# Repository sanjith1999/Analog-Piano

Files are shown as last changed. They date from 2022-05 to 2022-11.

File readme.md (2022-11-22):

## The Analog-Piano

The electronic pianos available in the markets are using a pre-recorded audio of the sound to generate the tones. The task of this project is explore the possible analog designs to synthesize a tone. In this report, we have discussed our views and experiences on a stable design for synthesizing middle octave c-Note. An audio amplifier design that improvises the generated sound quality and capable of driving mid-power speakers is included in parallel at each stage.

## Block Diagram
flow

## Circuit Diagram

### Amplifier
Capture

The complete report (downloadable) can be found [ here](https://github.com/sanjith1999/Analog-Piano/blob/master/Submission%20Files/Report/main.pdf)
<br>
<br>
### Breadboard Design
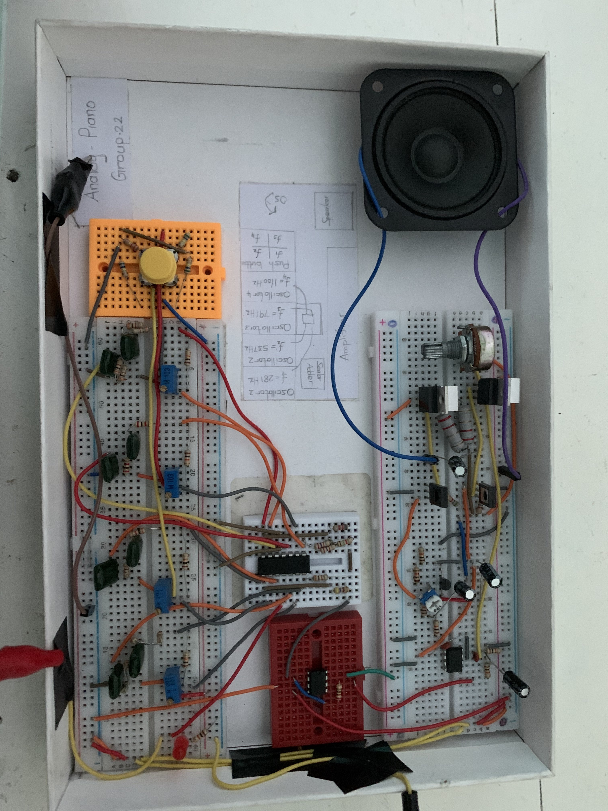
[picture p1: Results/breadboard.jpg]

<br>
<br>
<h3>Prototype</h3>
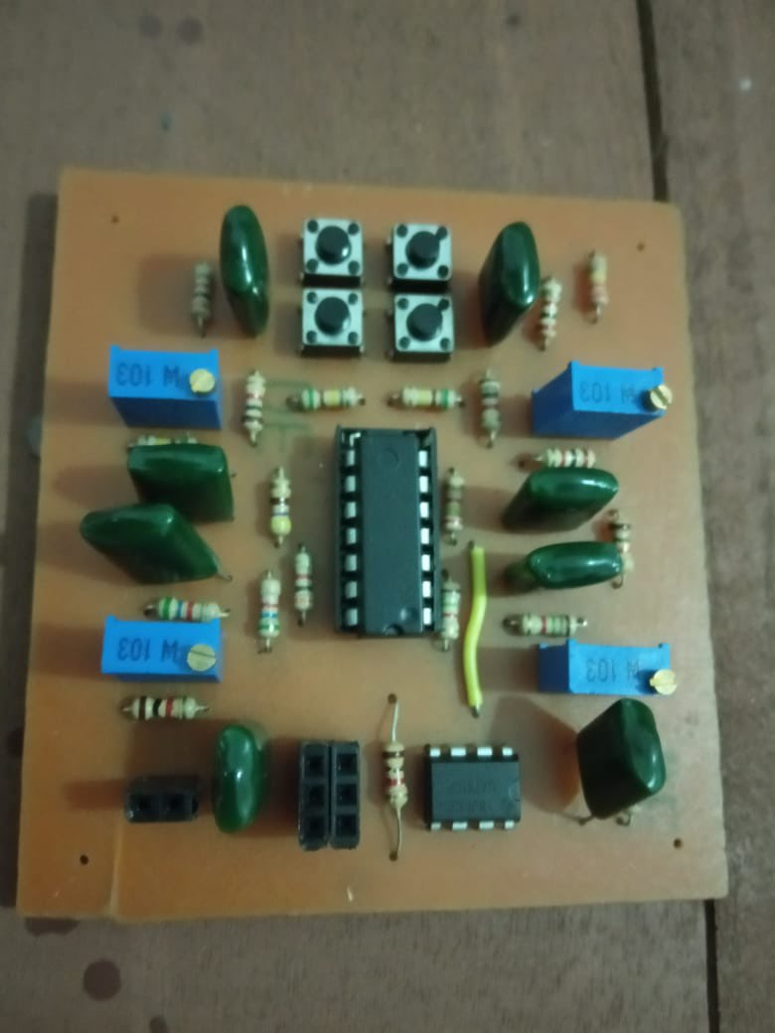
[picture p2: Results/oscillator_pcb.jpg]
Prototype Wave Generator

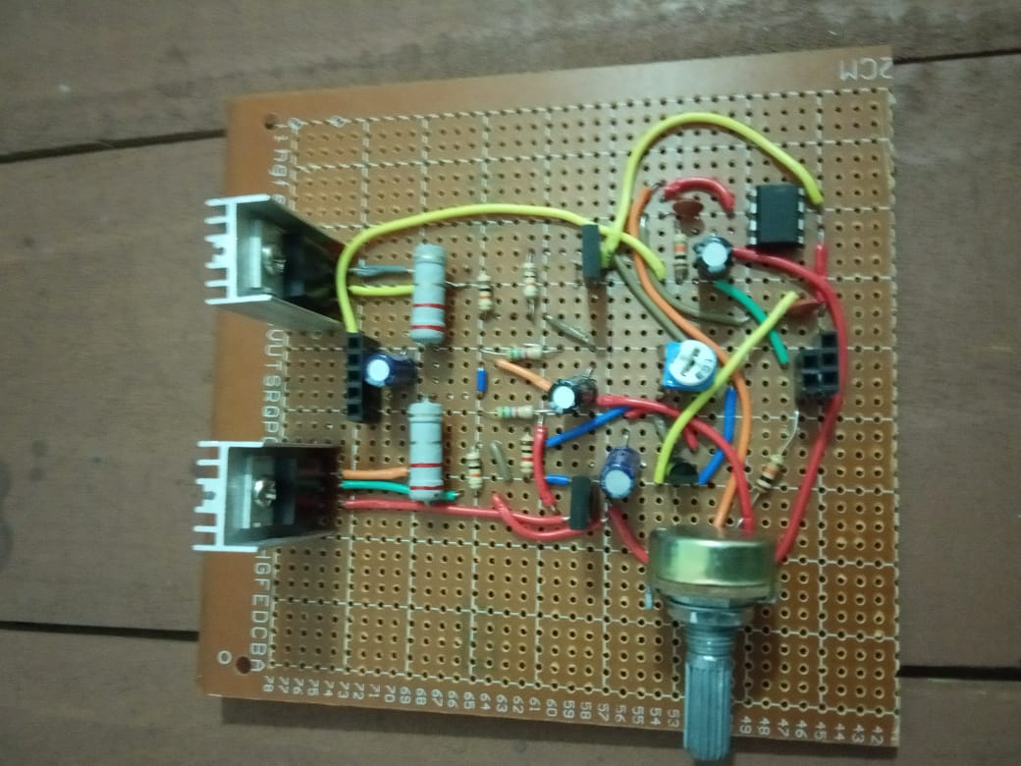
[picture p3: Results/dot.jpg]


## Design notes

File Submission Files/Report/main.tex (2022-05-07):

\documentclass[a4paper,12pt]{article}

\usepackage{./setting/preamble}
 
\begin{document}
\onecolumn
\input{sections/title}

\tableofcontents
\vspace*{1cm}
All the circuit virtual simulation circuits and results can be found \href{https://github.com/sanjith1999/Analog-Piano.git}{here.}
\vspace*{3cm}
\begin{abstract}
    The electronic pianos available in the markets are using a pre-recorded audio of the sound to generate the tones in a digital format. The task of this project is to explore the possible analog designs to synthesize a tone. In this report, we have discussed our views and experiences on a stable design for synthesizing middle octave c-Note. An audio amplifier design that improvises the generated sound quality and capable of driving mid-power speakers is included as the final stage of the design
\end{abstract}
\newpage

\twocolumn
\input{sections/introduction}
\input{sections/theory}
\newpage
\input{sections/methodology}
\newpage
\input{sections/results}
\input{sections/conclusion}
\newpage
\input{sections/appendix}
\end{document}

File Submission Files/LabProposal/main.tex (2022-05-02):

\documentclass[11pt]{article}

\usepackage{geometry}
 \geometry{
 a4paper,
 total={170mm,257mm},
 left=25mm,
 top=25mm,
 }

\title{Piano}
\author{Proposal : Group 22 }
\date{}
\date{\vspace{-5ex}}

\begin{document}
\maketitle
\section*{Description}
The piano can be considered as a simple starting point of fusing music into electronics.
The purpose of this project is to develop a piano with seven notes with only analog
electronic circuits.

\section*{Outcomes}
Design a piano that can generate sounds of frequencies associated with all the seven notes which
are sensible for the human ear. The piano sound must be amplified for the sake of making
it audible clearly. It is expected that the sound to be smoothened with noise-free
constraints to make it more enjoyable.
\subsection*{Skills}
\begin{enumerate}
    \item Hands-on experience with analog wave generation and wave addition.
    \item Designing amplifier circuits from scratch which can handle higher frequencies.
\end{enumerate}
\subsection*{Evaluation Criteria}
\begin{enumerate}
    \item Design: Neatness, and sustainability of the electronic circuit.
    \item Smoothness and audible level of output.
    \item The smoothness of sound during switching between notes.
\end{enumerate}

\section*{Additional Notes}
\begin{enumerate}
    \item Members are not allowed to use any kind of IC, Timers, or op-amps in the design of the project.
    \item Members are expected to have proper noise-cancelling strategies to make the sound enjoyable.
    \item Having a proper sound controlling mechanism to switch between sounds is considered a plus.
    \item Members are expected to implement techniques of pure wave generation and wave addition to achieve these requirements.
\end{enumerate}
\end{document}

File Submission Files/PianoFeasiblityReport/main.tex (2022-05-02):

\documentclass[10pt]{article}

\usepackage[left=3cm, right=3cm,top=2cm,bottom=2cm]{geometry}
\usepackage{tikz}
\usepackage{graphicx}
\usepackage{wrapfig}
\usetikzlibrary{shapes, arrows}

\font\myfont=cmr12 at 12pt
\setlength{\parindent}{8ex}

\newcommand\encircle[1]{\tikz[baseline=(X.base)] \node (X) [draw, shape=circle, inner sep=0] {\strut #1};}

\tikzstyle{block} = [draw, fill=red!20, rectangle,
minimum height=3em, minimum width=5em]
\tikzstyle{blockA} = [draw, fill=blue!20, rectangle,
minimum height=3em, minimum width=5em]
\tikzstyle{blockB} = [draw, fill=green!20, rectangle,
minimum height=3em, minimum width=5em]
\tikzstyle{sum} = [draw, fill=red!20, circle, node distance=2cm]
\tikzstyle{input} = [coordinate]
\tikzstyle{output} = [coordinate]
\tikzstyle{pinstyle} = [pin edge={-to,thin,black}]

\title{\bf{The Piano}}
\author{}
\author{\vspace{-2ex}}
\date{}
\date{\vspace{-2ex}}

\begin{document}

\begin{flushright}
    $_*$\underline{Group : 22}
\end{flushright}
\vspace{-10ex}
{\let\newpage\relax\maketitle}
\vspace{-12ex}
\section*{Introduction}
\vspace{-1.5ex}
Piano is one of the most pleasant musical instruments. It operates completely in a mechanical manner using vibration of differently tensed strings to produce musical notes. Our project idea is based on mimicking the operation using analog electronic components. Synthesizing signals with various frequencies and characteristics relevant to exact same notes which are produced by a real piano. This feasibility report will address the basic implementation strategies available in our analog design to generate a pleasant musical sound.
\vspace{-1ex}
\section*{Literature Review}
\vspace{-1.5ex}
Analog signal generator hidden inside the abstraction, is the starting point of most electronic circuits. Designs available in the market generate a variety of waveforms and frequency ranges according to the application. To generate a low-frequency sine-wave, available circuits engage a Wien bridge oscillator. This can be taken as the basic building block of piano since all tones can be visualized as the addition of different sine wave components. The concept of switching a connection with another circuit using a relay operation is common in analog design. This can be included in the piano design to mimic the action of the damping pedal.
\par
Old sound systems used an audio equalizer using RLC circuit to lower or boost certain frequency ranges specifically. This can be utilized in our piano to change the softness of the generated sound. In earlier days, most of the sound devices available in the market starting from simple analog radio up to studio speakers engaged voltage amplifiers to amplify the audio signal to a sustainable level. The circuit design of amplifiers also had the capability of removing dc offset which is a danger to the speaker.
\vspace{-1ex}
\section*{Block Diagram}
\begin{tikzpicture}[auto, node distance=3cm,>=latex']
    % We start by placing the blocks
    \node [blockA, name=keyInput] {key Input};
    \node [block, below of=keyInput,text width=2cm,yshift=1cm,xshift=1.5cm] (waveGenerator) {Wave Generator};
    \node[sum, right of =waveGenerator,text width=1cm,xshift=1cm](scalarAdder){Scalar Adder};
    \node[blockA, below of = keyInput,yshift=-1cm](pedal){Pedal};
    \node [block, right of = scalarAdder] (damper) {Damper};
    \node[block, below of = damper,yshift=1cm](switch){Relay Switch};
    \node [block, right of=damper,text width=2cm,, pin={[pinstyle]below:Extract Noise },node distance=3cm] (aE) {Audio Equalizer};
    \node[block, right of=aE](amplifier){Amplifier};
    \node[blockB,below of = amplifier,text width=2cm](speaker){Speaker Out};
    %\draw [->] (controller) -- node[name=u] {$u$} (system);
    %\node [output, right of=system] (output) {};

    % Once the nodes are placed, connecting them is easy. 
    \draw [draw,->] (keyInput.east) -| node {$\encircle{a}$} (waveGenerator.north);
    \draw [->] (waveGenerator) -- node {$\encircle{b}$} (scalarAdder);
    \draw[->](pedal) --node {} (switch);
    \draw[->](switch) --node {$\encircle{c}$} (damper);
    \draw[->](scalarAdder) --node {$\encircle{d}$} (damper);
    \draw[->](damper) --node {$\encircle{e}$} (aE);
    \draw[->](aE) --node {$\encircle{f}$} (amplifier);
    \draw[->](amplifier) --node {$\encircle{g}$} (speaker);
\end{tikzpicture}

\vspace{-8ex}
\section*{Analog Analysis}
\begin{itemize}
    \item[] $\encircle{a} : $ Analysing resistor values to be used in Wein-bridge that suit required frequency generation.
    \item[] $\encircle{b} : $ Pureness of sine waves generated with fundamental and over tone frequencies.
    \item[]  $\encircle{c} : $ Analysing the possiblity of switching and holding the damping operation.
    \item[] $\encircle{d} : $ Addition of the harmonic components according to the amplitude ratio.
    \item[] $\encircle{e} : $ Analyzation of exponential decay of audio signal.
    \item[] $\encircle{f} : $ Analyzing softness of sound by scaling different frequecy ranges.
    \item[] $\encircle{g} : $ Anlysing the output audio signal with different amplifiaction factor.
\end{itemize}

\section*{Methodology}

\subsubsection*{Analyzation of Piano Notes}
\vspace{-1.5ex}
Analyzing the frequency spectrum of sounds from each note of the piano, as to mimic the exact spectrum through the addition of sine waves.
\vspace{-1.5ex}
\subsubsection*{Wave Generation}
\vspace{-1.5ex}
We have decided to implement the Wein Bridge oscillator circuit to generate sine waves spans in the audio frequency range. The circuit allows modification of frequencies by interchanging values of resistance used. This character can be utilized to map the keys with corresponding wave generation.
\vspace{-1.5ex}
\subsubsection*{Damping of Audio Signals}
\vspace{-1.5ex}
As a step of mimicing the sound from Piano we need to decay the audio signal in an exponential manner. As of now, it is decided to implement some strategy to compensate the energy stored in wave inorder to get a decay in loudness with time.
\vspace{-1.5ex}
\subsubsection*{Amplification}
\vspace{-1.5ex}
As a step of getting audible sound from the piano, we decided to implement a amplifier circuit using  BJTs.
\vspace{-1.5ex}
\subsubsection*{Pedal Action}
\vspace{-1.5ex}
The action of damping pedals in the piano can be mimicked by changing the damping factor of the damper. As the initial step of implementing the pedal action, it is decided to isolate and engage the damper from the circuit in action.  To increase the closeness of the design with a real piano, it is also considered about including a switch to make the output sound softer in general.
\vspace{-1.5ex}
\subsubsection*{Audio Equalizer}
\vspace{-1.5ex}
Audio Equalizer softens the sound wave to give a pleasurable experience from the piano. The design of the equalizer consists of frequency filters.  It separates the sound signal under frequency categories and boosts or lowers its amplitude as per preference.
\vspace{-1.5ex}
\section*{Preliminary Results}
\vspace{-1.5ex}
As the early-stage process of our project, we were able to synthesize the sound of piano notes using only eight harmonics sine waves of corresponding frequecy. The following image shows the normalized frequency spectrum of original and regenerated audio signals. Although we were able to observe differences in damping patterns, the sounds of both the signals heard very much similar. It is also considered about implementing multiple dampers and adding compressed signals to bring the sound more magnetized towards the real one.
\begin{figure}[h]
    \centering
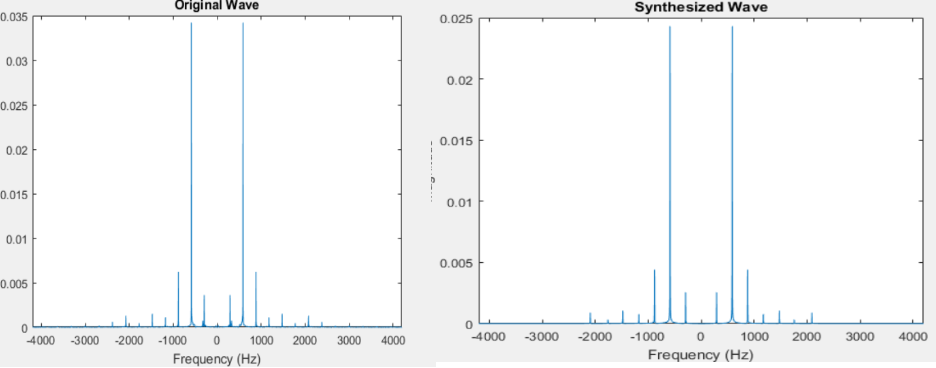
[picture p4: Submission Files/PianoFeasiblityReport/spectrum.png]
    
\end{figure}
\vspace{-1.5ex}
\section*{References}
1. Synthesizing Frequency of Notes $\to$ https://web.eecs.utk.edu/~hqi/ece505/project/proj1.pdf
\newline
2. Wave Generation $\to https://en.wikipedia.org/wiki/Wien$\_$bridge$\_$oscillator/$
\newline
https://www.homemade-circuits.com/simple-sine-wave-generator-circuits/
\newline
3. Mathematics of Sound $\to$ https://www.ams.jhu.edu/dan-mathofmusic/sound-waves/
\newline
4. Similar Project with High Scope $\to$ http://www.jiisuki.net/reports/howto-build-analog-synth.pdf
\newline
5. Audio Equalizer $\to$ https://circuitdigest.com/electronic-circuits/audio-equalizer-tone-control-circuit-with-bass-treble-and-mid-frequency-control

\end{document}

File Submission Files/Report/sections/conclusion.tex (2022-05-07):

\section{Conclusion}
We were able to complete the project within the given period. Most of the design expectations were achieved. From stable output waves from oscillator up to scaling of each harmonic in the spectrum were finely aligned with expectation. The stability in the gain of the output from the amplifier was adapted even in the situations of thermal-run-away. A better quality equalized sound is accomplished as the overall exploration of the project. 
\par
However, some of the design parameters could not be fully met. The phases of each harmonics could not be able to control rather than fine-tuning the oscillator gains. The amplifier design does not meet the expected efficiency and bandwidth range. While it meets the lower cutoff requirement, the upper cutoff is lower than(12kHz) expectation(20kHz). The best-achieved envelope pattern had elongation in the beginning. The final prototype on the PCB couldn't be able to complete due to the poor quality of the tracks.
\subsection*{Discussion}
\begin{itemize}
    \item Although the wave generator did a fine job with synthesizing c-wave, too many tuning parameters and complexity in combining oscillators make it hard to achieve such a feasible end-product as complete piano with this strategy.
    \item There is a large amount of heat dissipated by the TIP transistors. Heat sinks attached to them failed to compensate for enough heat in the longer run. Thermal-run-away behavior was observed which hindered circuit performance with time. 
    \item The values obtained by the virtual simulation did not agree with the values obtained through the physical prototype. However, the specification sheet has been based on the prototype values. Therefore, the specification sheet will be an accurate representation of the performance.
\end{itemize}
\onecolumn
\section*{References}
\begin{enumerate}
    \item \href{https://web.eecs.utk.edu/~hqi/ece505/project/proj1.pdf}{Synthesis of Musical Notes andInstrument Sounds with Sinusoids}
    \item \href{https://electronics.stackexchange.com/questions/178975/is-it-feasible-to-synthesise-sound-with-analog-circuitry-these-days}{Feasiblity about synthesizing sound with analog
              circuitry}
    \item \href{http://www.vibrationdata.com/piano.htm}{Original Sounds of Piano}
    \item \href{https://universe-review.ca/R12-03-wave02.htm}{Wave, Sound, and Music}
    \item  \href{https://en.wikipedia.org/wiki/Wien_bridge_oscillator}{Weinbridge-Oscillator}
    \item \href{https://www.homemade-circuits.com/simple-sine-wave-generator-circuits/}{Alternative sine wave generators}
    \item \href{https://www.ams.jhu.edu/dan-mathofmusic/sound-waves/}{Mathematics behind wave manipulation}
    \item \href{http://www.jiisuki.net/reports/howto-build-analog-synth.pdf}{How to Design and Build an Analog Synthesizer from Scratch}
\end{enumerate}
\vspace*{5cm}
\section*{Contribution}
\begin{tabular}{|l|l|l|}
    \toprule
    ID NO                    & Member                              & Contribution                                           \\
    \midrule\midrule
    \multirow{2}{*}{190562G} & \multirow{2}{*}{S.Sanjith}          & Damper Design, Improvisation of Amplfier Design,       \\
                             &                                     & Routing of PCBs, Data Sheet Design                     \\
    \midrule
    \multirow{2}{*}{190557V} & \multirow{2}{*}{K.G.C.P.Sandaruwan} & Oscillator Design, Scalar Adder Design                 \\
                             &                                     & Oscillator Schematic Design                            \\
    \midrule
    \multirow{2}{*}{190539T} & \multirow{2}{*}{T.Sajeepan}         & Analyzation of Original Wave, Amplifier Design(basic), \\
                             &                                     & Amplifier schematic design                             \\
    \midrule
    190543B                  & G.S.M.U.K.Samarakoon                & Contribution to Amplifier Design                       \\
    \bottomrule
\end{tabular}

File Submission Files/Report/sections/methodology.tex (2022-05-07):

\section{Methodology}
\subsection{Preliminary Analysis}
At an earlier stage of the project, it is planned to build an octave piano with twelve notes including minor keys. At that stage, we analyzed the frequency spectrum of each note and found out it is possible to produce a majority feeling of sound with only four harmonics to a given note.
\par
After synthesizing all the keynotes from its harmonics using Matlab, we moved to circuit development. At this stage, it is decided to stimulate only one note from the piano because the generation of notes is modularizable. For this purpose, the C-wave have chosen  which is in the middle of the spectrum.
\begin{figure}[h]
    \centering
    \begin{subfigure}{.9\columnwidth}
        \centering
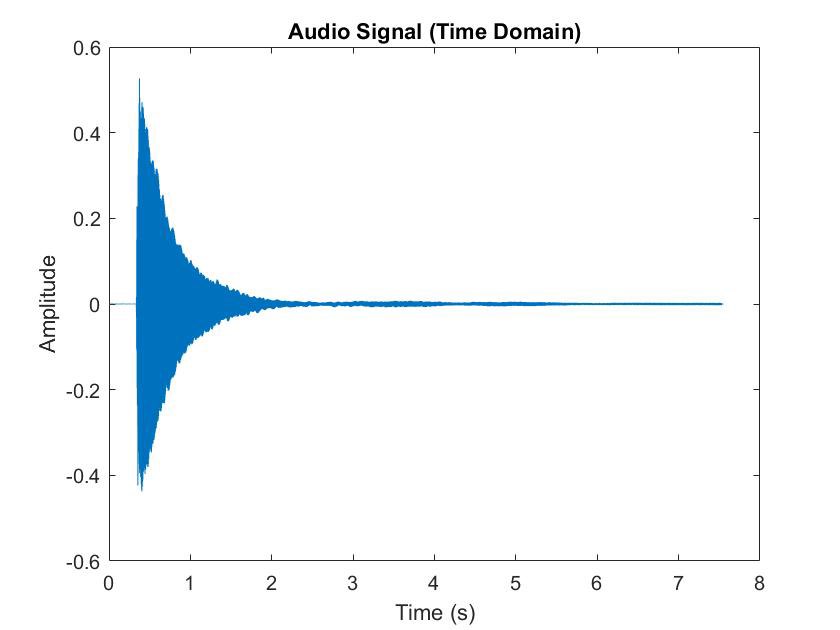
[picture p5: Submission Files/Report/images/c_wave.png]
        
    \end{subfigure}
    \newline
    \begin{subfigure}{.9\columnwidth}
        \centering
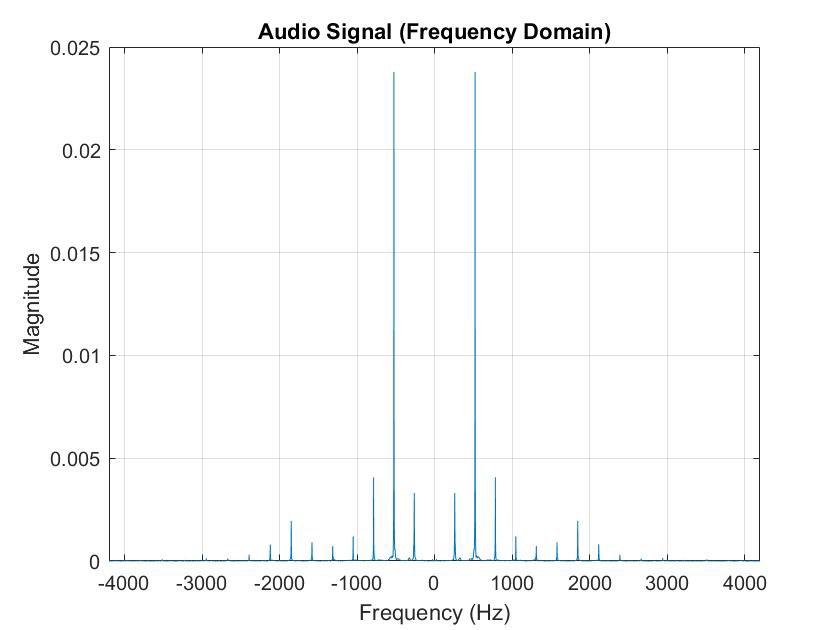
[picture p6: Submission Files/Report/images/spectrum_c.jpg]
        
    \end{subfigure}

\end{figure}
\subsection{Circuit Design}
The key components of the circuit are illustrated below in the block diagram. Before moving to the prototype all the circuits are simulated using NI Multism.Working simulation models of all the circuits can be found in the git-repository.
\begin{figure}[h]
    \begin{center}
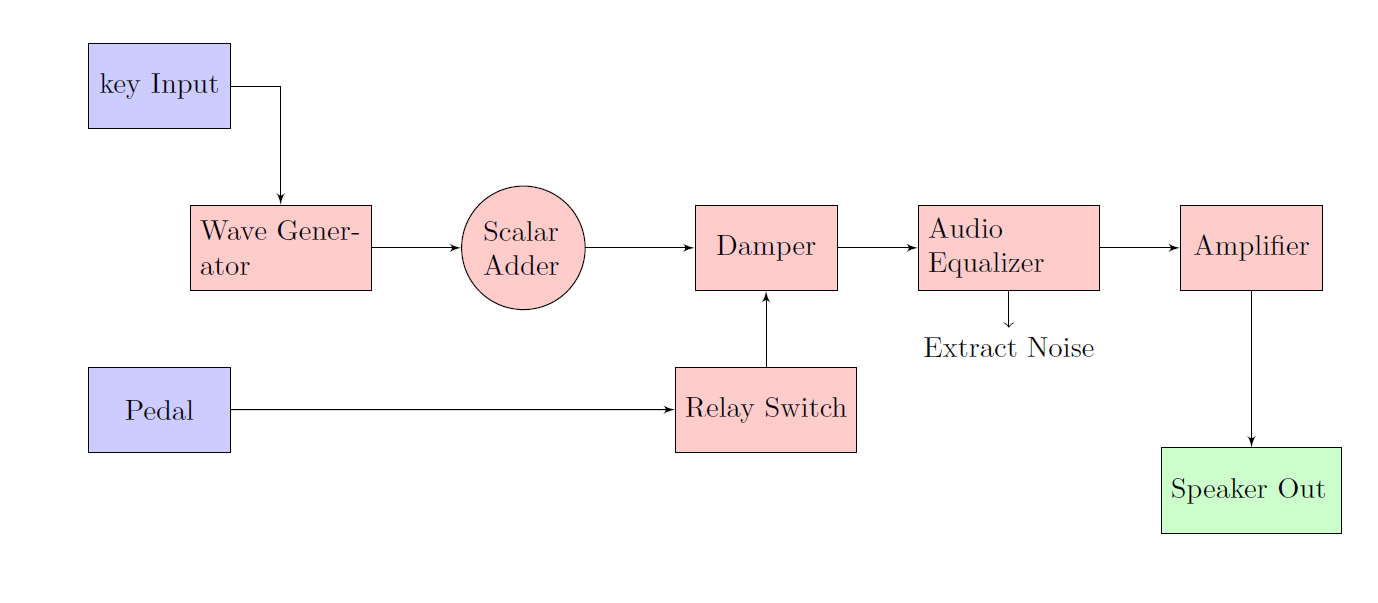
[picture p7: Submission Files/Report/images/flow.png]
        
        \caption*{Block Diagram of the Circuit}
    \end{center}
\end{figure}
\subsubsection{Wave Generator}
Square wave generation of half the frequency together with a bandpass active filter is considered in the first stage of the circuit development. Need for achieving a larger Q factor for the filter as the number of harmonics increases, lift the choice to not-feasible.
\par
Moving towards a stable solution brought the Wien bridge oscillator into play. These oscillators have the flexibility over frequency choice ($\frac{1}{2\pi RC}$) making them the most suitable option to be used with modularizable piano.
\subsubsection{Key and Pedal}
After a clear analysis of the waveform using Matlab, it is expected to achieve an exponential decay in the waveform once the oscillation is triggered. Looking at the discharging behavior of the capacitor initially it is decided to engage a capacitor together with an analog multiplier to form an envelope around wave output.
\par
Due to the power inefficiency of the design and difficulty in finding good quality multipliers, the design moved to engage tuning of negative feedback of oscillator to achieve necessary output. This is further utilized to mimic the damping pedal of the piano by controlling the elongation of the signal-out of each oscillator.
\subsubsection{Scalar Adder}
Direct connection between outputs of oscillators even after scaling leads to interference in the signal generation stage of the oscillator. In contrast, using a scaling adder we can provide a low impedance output path while scaling the inputs as specified.
\subsubsection{Amplifier}
At earlier stages, the amplifier was implemented in class-A configuration. The requirement for lower output resistance of the bias path leads to high power dissipation in the signal-free state. This made such a model not practical without huge heatsinks at the cost of low power efficiency.
\begin{figure}[h]
    \begin{center}
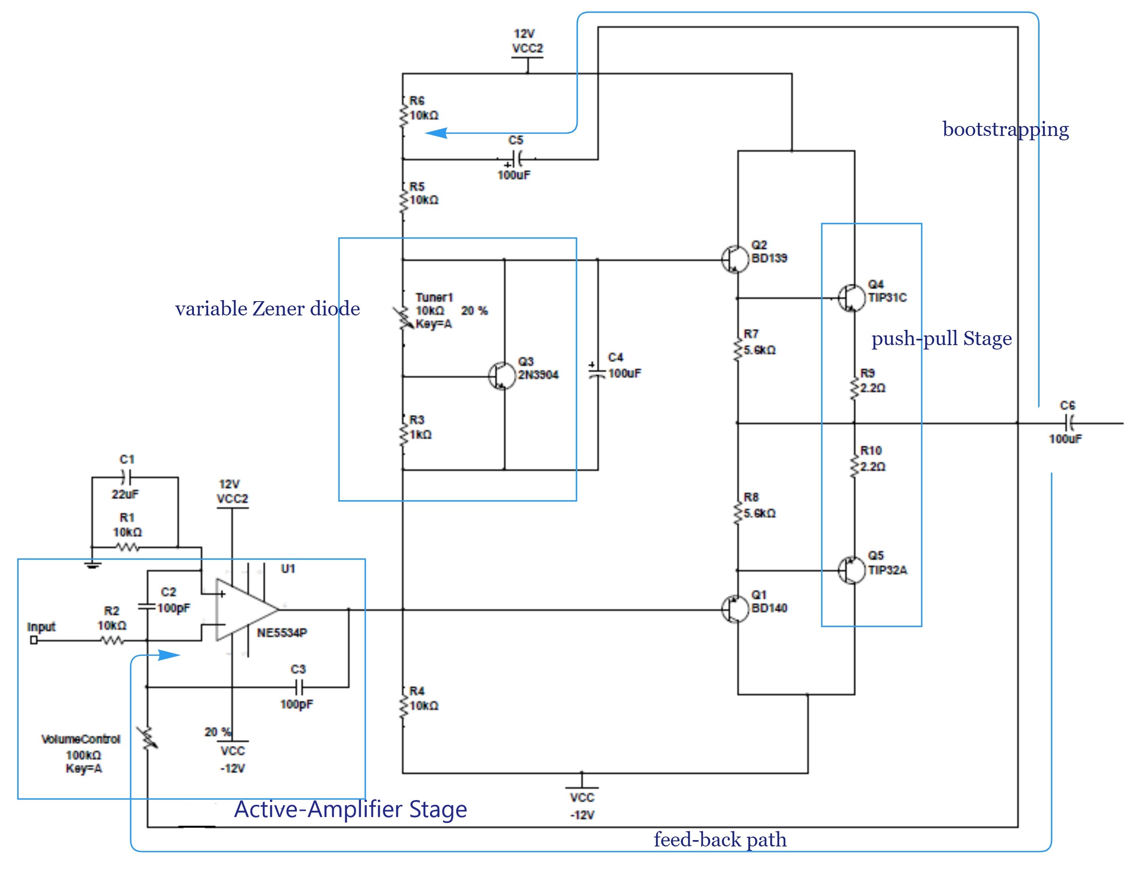
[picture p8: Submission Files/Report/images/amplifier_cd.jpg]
        
    \end{center}
\end{figure}
\\
\textbf{Active Amplifier Stage}: In the first part of the amplifier design an op-amp is used in the inverting configuration. The feedback path is connected to the end of the overall circuit to ensure enough current supply available in the output.\\
The op-amp NE5534 was chosen for the purpose according to its key characteristics such as high unity-gain bandwidth(10MHz), very low harmonic distortion,high common mode rejection ratio(100dB). The capacitance values of C2 and C3 are chosen to allow only higher frequencies ($>20kHz$) to pass through. These are utilized in a manner to remove high-frequency noises from the wave-form.
\\
\\
\textbf{Push-Pull Stage}: Considering the requirement of high power gain it is decided to engage Darlington pairs for this purpose. These components failed in the long run due to the inability of compensating for high power dissipation. Considering this, the design moved to engage two coupled BJTs to allow the choices for transistors to be used in the high current path. The similar pairs TIP31C and TIP32C were chosen after considering their high power compensation capability(around 40W).
\\
\\
\textbf{Bias}: Due to the requirement for a sudden supply of high current on the keypress, the signal gets noisy when we drive the speaker without any bias. In earlier stages, a few diodes are used to bias the circuit which failed to get rid of the noise. As the next step, we used Zener diodes that provide the capability to choose higher bias voltage. This results in the low efficiency of the circuit.
After considering all the methods it is decided to implement the variable Zener diode which has the flexibility over varying bias voltage in a wider range. This provides control over two extremities, effecieny and quality of the output.
\\
\\
\textbf{Bootstrapping}: The capacitor C5 gets charged to the pre-decided bias voltage.  By maintaining the circuit time constant very large ($t=R5\parallel R6\star C5>0.5S$) the overall bias voltage of the circuit is maintained at a constant value through-out the signal time.

\subsection{Prototype Design}
\begin{figure}[h]
    \begin{minipage}{.53\columnwidth}
        At earlier stages, a virtual prototype was developed using Multisim(see Appendix A), and many of the tests were carried out on this program itself. Afterward, the model is moved to the breadboard in a modular manner and the outputs at each stage were tested independently.
    \end{minipage}
    \begin{minipage}{.38\columnwidth}
        
    \end{minipage}
\end{figure}

As the final step of implementation, PCB for the physical prototype was designed using Altium (see Appendix B for layout). This was then screen printed and the relevant components soldered to the PCB. Finally, heatsinks were mounted accordingly to ensure safer operation.
\subsection{Components}
\subsubsection*{Wave Generator}
The resistance and capacitance values corresponding to the filter circuit of each frequency in the oscillator are indicated below in the table. The normalized content ratio and resistance used in the input path of the scalar adder are also appended together.
\begin{center}
    \begin{tabular}{|c|c|c|c|c|}
        \toprule
        f    & \multicolumn{2}{|c|}{Oscillator} & \multicolumn{2}{|c|}{Scaling}                         \\
        \cmidrule{2-5}
        (Hz) & R(k$\Omega$)                     & C(nF)                         & $\eta$ & R(k$\Omega$) \\
        \midrule
        281  & 5.67                             & \multirow{4}{*}{100}          & 0.1386 & 3.03         \\
        537  & 2.96                             &                               & 1      & 420          \\
        791  & 2.01                             &                               & 0.168  & 2.5          \\
        1087 & 1.44                             &                               & 0.051  & 8.33         \\
        \bottomrule
    \end{tabular}
\end{center}

Easily available 4-quad op-amp LM341 was chosen for oscillators. This allowed having a compact design in prototyping. UA751 op-amp is used in the scalar adder stage and 220$\Omega$ is used as feedback resistance to ensure the addition of all four waves sits in the supply range.
\subsubsection*{Amplifier}
The following list of elements is used in the amplifier stage to allow only the frequency in the audible range to pass through and to withstand high power dissipation.
\begin{enumerate}
    \item Capacitors :
          \begin{tabular}{l r}
              22$\mu$F  & 1 \\
              100$\mu$F & 1 \\
              100pF     & 2 \\
          \end{tabular}
    \item Resistors :
          \begin{tabular}{l r}
              10k$\Omega$  & 5 \\
              1k$\Omega$   & 1 \\
              5.6k$\Omega$ & 2 \\
          \end{tabular}
    \item Presets :
          \begin{tabular}{l r}
              10k$\Omega$  & 1 \\
              100k$\Omega$ & 1 \\
          \end{tabular}
    \item Power Resistors :
          \begin{tabular}{l r}
              2.2$\Omega$ & 2 \\
          \end{tabular}
    \item Transistors :
          \begin{tabular}{l r}
              2N3904        & 1 \\
              TIP31C,TIP32C & 1 \\
              BD139,BD140   & 1 \\
          \end{tabular}
    \item Op-Amp : NE5534P   1
\end{enumerate}

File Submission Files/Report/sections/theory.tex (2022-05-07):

\section{Theory}
\subsection{Oscillator}
\begin{wrapfigure}{l}{0.50\columnwidth}
  \vspace*{-.5cm}
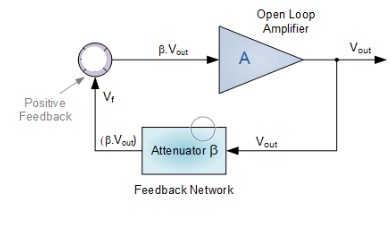
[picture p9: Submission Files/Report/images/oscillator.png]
  
  \vspace*{-.8cm}
\end{wrapfigure}

An oscillator is an amplifier that uses positive feedback that generates an output frequency without the use of an externally applied input signal. Once the oscillation is started, the parameters A and $\beta$ are aligned to maintain a unity gain at the required frequency in order to keep the oscillation indefinitely stable.

\subsubsection*{Wein-Bridge Oscillator}
The Wien Bridge Oscillator uses a feedback circuit consisting of a series RC node cascaded with a parallel RC of the same component values producing a phase delay or phase advance circuit depending upon the frequency. Effectively they act as a second-order frequency dependant Band-Pass-Filter with a high Q factor at the selected frequency $f_r=\frac{1}{2\pi RC}$. This RC network is connected in the positive feed-back path of the amplifier and has zero phase shift at just one frequency.
\par
Other part of the feedback signal is connected to the inverting input terminal(negative feed-back) via resistor divider network of $R_1\&R_2$. Then at the selected resonant frequency($f_r$), the voltages applied to the inverting and non-inverting inputs will be equal and “in-phase”. So the positive feedback will cancel out the negative feedback signal causing the circuit to oscillate.

\begin{figure}[h]
  \begin{subfigure}{.58\columnwidth}
    \centering
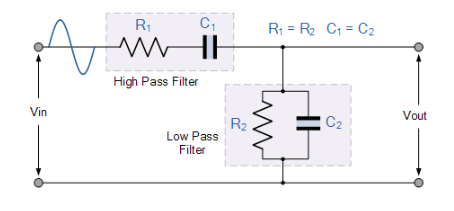
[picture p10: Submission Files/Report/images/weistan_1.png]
    
    \caption*{RC-Network}
  \end{subfigure}
  \begin{subfigure}{.38\columnwidth}
    \centering
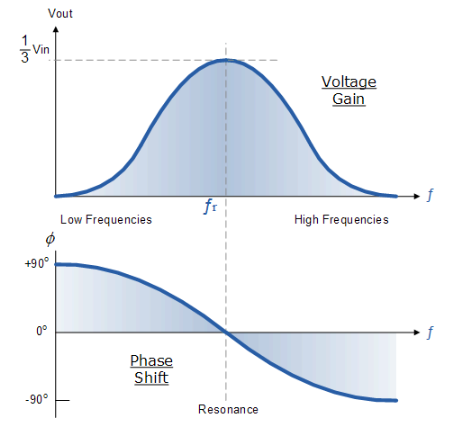
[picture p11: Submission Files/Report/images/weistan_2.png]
    
    \caption*{Response}
  \end{subfigure}
  \newline
  \centering
  \begin{subfigure}{.65\columnwidth}
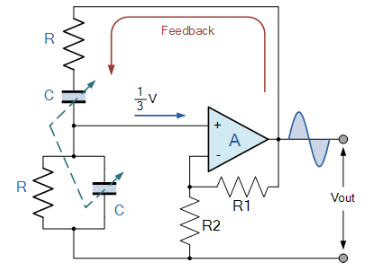
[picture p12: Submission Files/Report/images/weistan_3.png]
    
    \caption*{Oscillator}
  \end{subfigure}
\end{figure}
\subsubsection*{Starting and Damping Oscillation}
By controlling the negative feedback ratio($\frac{R_2}{R_1+R_2}$) of the oscillator we can start and damp the oscillation as required. To start oscillation, we need to slightly reduce the negative feedback($<\frac{1}{3}$). This will give rise to a resultant signal on the amplifier input side which is get amplified and fed back recursively turns out to drive oscillation.
\par
Keeping the feedback ratio slightly more ($>\frac{1}{3}$) will give rise to a resultant negative input which is get added adversely with output resulting in damping of the oscillation. By fine-tuning the ratio in a very elegant manner, it is possible to control the damping time constant.
\subsection{Amplifier}
Driving a high-power (3W) speaker draws a high amount of current from the circuit. These current ranges are very much higher than the maximum supply available from op-amps and other low power components used in generating the wave patterns. So it is crucial to maintain an amplifier boundary between low power noisy signal to high power driving signal free of noise. In the following context, we will discuss the theories behind our amplifier design in detail.
\subsubsection*{Class-A }
\begin{figure}[h]
  \begin{center}
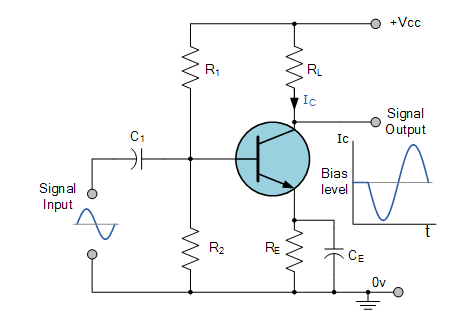
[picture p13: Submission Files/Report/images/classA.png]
    
    \vspace*{-.5cm}
  \end{center}
\end{figure}
These are the simplest configuration among other families. It uses a single-ended transistor for its output stage with the resistive load connected directly to the Collector terminal. When the transistor switches “ON” it sinks the output current through the Collector resulting in an inevitable voltage drop across the Emitter resistance thereby limiting the negative output capability.
\par
The current handling capability of such an amplifier family can be increased drastically by replacing the output transistor with the structure of \textbf{Darlington pair}. These devices provide high input impedance.
\subsubsection*{Class-B}
Class B Amplifiers are biased to only conduct half of the input signal. Using 2 such amplifiers arranged in a “Push-Pull” configuration, and combining the output signal, the full waveform can be obtained.
\par
As the quiescent current for this amplifier is 0, there is little or no DC, therefore much less power dissipation. However, there is a slight waveform distortion due to the bias voltage requirement of the transistor known as cross-over distortion.
\subsubsection*{Class-AB}
Class AB amplifiers overcome the distortion issue of class B amplifiers by permanently bringing the two transistors just into the active region. This reduces the efficiency, but results in an undistorted the waveform in the output.
\par
\begin{figure}[h]
  \vspace*{-.2cm}
  \begin{center}
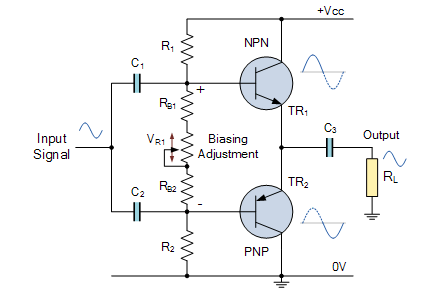
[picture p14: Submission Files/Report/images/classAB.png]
    
  \end{center}
  \vspace*{-.5cm}
\end{figure}
As the power dissipation due to the DC component is much less than class A amplifiers, these circuits allow the use of compact heat sinks during the operation.
\subsubsection*{Variable Zerner Diode}
\begin{figure}[h]
  \begin{minipage}{.68\columnwidth}
    This variable Zener diode circuit acts like a Zener diode with a breakdown voltage adjustable in a vast domain. This is achieved by driving a BJT in the active region and controlling the base current.
  \end{minipage}
  \begin{minipage}{.3\columnwidth}
    \begin{center}
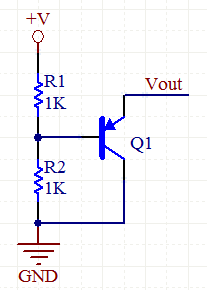
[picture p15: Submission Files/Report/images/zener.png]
      
    \end{center}
  \end{minipage}
  \vspace*{-.5cm}
\end{figure}
The current through the voltage divider $R_1\&R_2$ must be higher compared to the base current.

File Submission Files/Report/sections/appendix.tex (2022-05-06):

\appendix
\section{Circuit Design}
\subsection*{Wave Generator}
\begin{figure}[h]
    \centering
    
    \vspace*{-5cm}
\end{figure}
\subsection*{Amplifier}
\begin{figure}
    \centering
    \vspace*{-6.5cm}
    
\end{figure}
\newpage

\section{Layout}
\begin{figure}[h]
    
    \begin{subfigure}{\textwidth}
        \centering
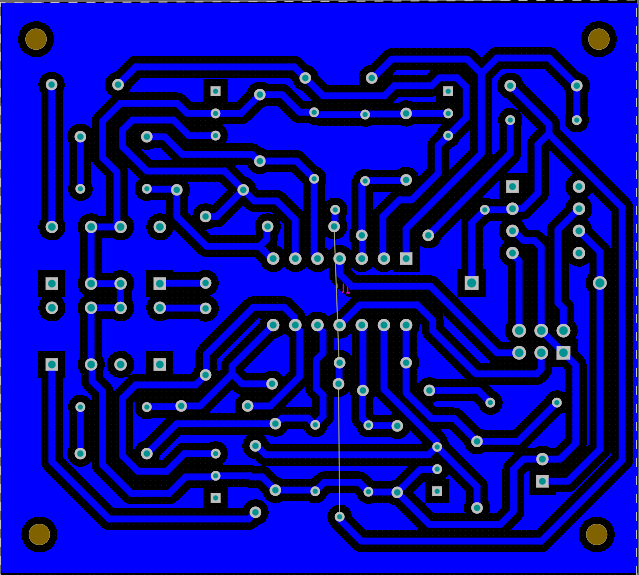
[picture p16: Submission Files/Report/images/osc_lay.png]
        
        \caption{\textbf{PCB-I} : Wave Generator}
    \end{subfigure}
    \vspace*{.5cm}
    \begin{subfigure}{\textwidth}
        \centering
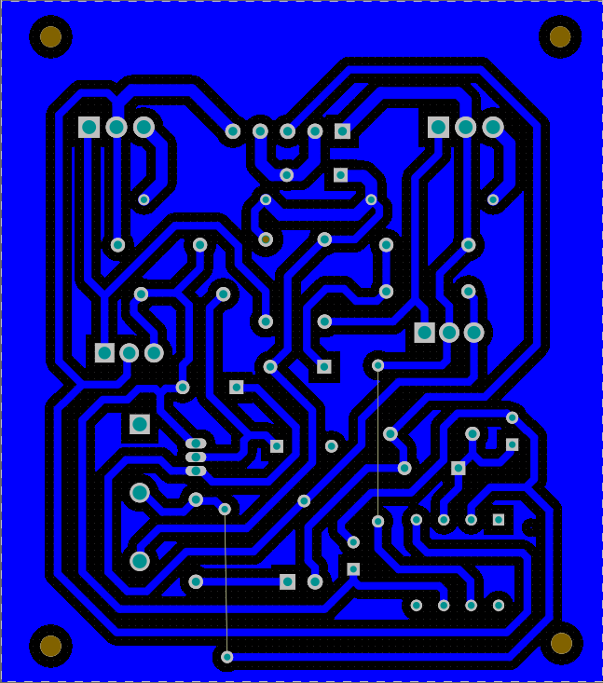
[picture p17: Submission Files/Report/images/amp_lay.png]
        
        \caption{\textbf{PCB-II} : Amplifier}
    \end{subfigure}
\end{figure}
\section{Datasheet}
The datasheet of the model is as follows...
\includepdf[pages=-]{sections/datasheet}

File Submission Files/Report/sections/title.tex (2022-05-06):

\begin{titlepage}

    \center

    % University
    \textsc{\Large Department of Electronic and Telecommunication}\\[.4cm]
    \textsc{\Large University of Moratuwa}\\[1cm]

    % Document info
    \textsc{\Large EN2090 : LABORATORY PRACTICE-II}\\[0.2cm]
    \textsc{\large }\\[1cm] 										% Course Code
    \HRule \\[0.5cm]
    { \LARGE \bfseries The Analog-Piano}\\[0.3cm]
    \HRule \\[1.5cm]
    \large
    \begin{center}
        \begin{tabular}{l l}
            \multicolumn{2}{c}{\textbf{Team : Dream Epic}} \\\\
            S.Sanjith  & 190562G \\
            T.Sajeepan & 190539T \\
            K.G.C.P.Sandaruwan  & 190557V \\
            G.S.M.U.K.Samarakoon & 190543B \\
        \end{tabular}
    \end{center}
\vspace*{1cm}
    {\Large \today}\\[1cm]
    \\[2cm] 
    \HRule\\
    \begin{flushleft}
        \vspace*{-.4cm}
        \emph{Our sincere thanks to Mr.Bhanuka Silva.}
    \end{flushleft}
    \vfill
\end{titlepage}

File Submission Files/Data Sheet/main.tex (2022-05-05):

\documentclass[a4paper,12pt,oneside,pdflatex,italian,final,twocolumn]{article}

\usepackage[utf8]{inputenc}
\usepackage{parallel}
\usepackage{siunitx}
\usepackage{booktabs}
\usepackage{fancyhdr}
\usepackage{caption}
\usepackage{multirow}
\usepackage{gensymb}
\usepackage[export]{adjustbox}
\usepackage[margin=0.5in]{geometry}
\addtolength{\topmargin}{0in}

\usepackage{libertine}
\renewcommand*\familydefault{\sfdefault}  %% Only if the base font of the document is to be sans serif
\usepackage[T1]{fontenc}

\graphicspath{{./images/}}

\title{Piano Datasheet}
\author{Team : Dream Epic }
\date{\today}

\begin{document}

\pagestyle{fancy}

\lhead{ENTC}
\chead {\today}
\rhead{Datasheet v1}

\onecolumn

\begin{figure}
    \begin{minipage}{0.47\textwidth}
        \centering
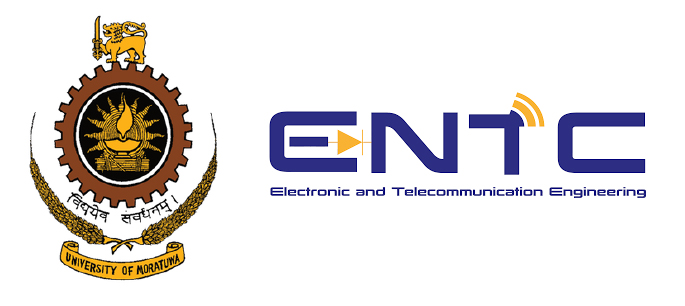
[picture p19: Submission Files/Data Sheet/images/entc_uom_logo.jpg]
        
    \end{minipage}
    \hfill
    \begin{minipage}{0.47\textwidth}
        \raggedleft
        \Huge \textbf{The Analog Piano}
    \end{minipage}
\end{figure}

\begin{figure}
    \begin{minipage}{0.65\textwidth}
    \section{Overview}
 The device is a sound synthesizer that mimics the sound of c-wave similar to that of a piano, on keypress.  A speaker(8$\Omega$ preferred) ranges around 3W can be used with the pinout to observe the sound output. The volume of the speaker and the noise level can be adjusted according to user interest. The components in the device can be adjusted according to one's interest to mimic a complete piano by implementing many such modules. The amplifier alone can be used to drive small speakers from the low power signal output of simple devices such as mobile phones. 
    \end{minipage}
    \hfill
    \begin{minipage}{0.3\textwidth}
        \centering
        
    \end{minipage}
\end{figure}

\section{Description}
As illustrated in the block diagram below the device consist of four oscillators which are fired by a push button. These oscillators mimic the first four harmonics which are strong enough to model the c-keynote. The triggered signals get added and scaled accordingly through a scalar adder. The output is filtered and amplified before reaching the speaker. Damping time of the wave can be controlled via the damping mechanism attached through a variable resistor with each oscillator. These can be used to mimic the functionality of the damping pedal by increasing their values.
\par
The preset in the amplifier block is allowed to tune by the user to get a noise-free output. For longer usage, it is recommended to keep the preset at a lower value which affects the power efficiency of the circuit. It is expected to use the device not more than fifteen minutes continuously which may harm the operation of the amplifier. Heat sinks used in the amplifier can reach up to 100$\degree$C. It is not advisable to touch them during the continuous operation of the synthesizer.
\par
The maximum current drawn by the oscillator and scalar adder is less than 5mA. Due to such a lower requirement, it is omitted in the technical specifications.
\begin{figure}[h]
    \centering
    
    \caption{Circuit Block Diagram}
\end{figure}
\newpage
\section{Technical specification}
Specifications are indicated for each module even though it pin-out of the device is narrower. This is done in the belief of allowing the users to make use of this to combine such modules in the creation of complete piano.\\
\vspace{-.5cm}
\begin{figure}[h]
\begin{minipage}{\textwidth}
\begin{center}
\begin{tabular}{|c|c|c|c|}
     \multicolumn{4}{l}{\textbf{Oscillators}}\\
    \toprule
     Operational  & Operational  & Decaying Control  & Output \\
     Voltage(V) & Frequencies(Hz)& Range(ms) & Impedance($k\Omega$)\\
    \midrule
   \multirow{4}{*}{3-6} & 281$\pm$3 & 300$\pm$100 & 2.49 \\
     & 537$\pm$3 & 300$\pm$120 & 0.44 \\
     & 790$\pm$5 & 300$\pm$150 & 2.37 \\
     & 1100$\pm$5 & 300$\pm$200 & 7.43 \\
    \bottomrule
\end{tabular}
\end{center}
\end{minipage}

\begin{minipage}{\textwidth}
\vspace{.8cm}
\begin{center}
    \begin{tabular}{|c|c|c|c|}
     \multicolumn{4}{l}{\textbf{Scalar Adder}}\\
    \toprule
     Operational  & Allowed Frequency & Recommended Resistance  & Output \\
     Voltage(V) & Range(Hz) & Range($k\Omega$) & Impedance($k\Omega$)\\
    \midrule
    9-12 & 20-20000 & 0.5-50 & 4.53\\
    \bottomrule
\end{tabular}
\end{center}
\end{minipage}

\begin{minipage}{\textwidth}
\vspace{.8cm}
\begin{center}
    \begin{tabular}{|l|c|c|}
     \multicolumn{3}{l}{\textbf{Amplifier}}\\
    \toprule
       & Unit & Value \\
    \midrule
    Operational Voltage & V & 9-12\\
    Current Requirements & A &0.08-0.5\\
    Input Impedance(Ac) & $M\Omega$ & 43$\pm$5\\
    Output Impedance(Ac) & $\Omega$&$10\pm5$\\
    Operational Frequency Range & Hz &200-12000\\
    Volume Control Range & dB & 20-70\\
    Achievable Power Efficiency &  & 63\%\\
    
    \bottomrule
\end{tabular}
\end{center}
\end{minipage}
\end{figure}

\raggedright
\vspace{-.5cm}
\section{Pinout}
\begin{minipage}{.48\textwidth}
\begin{center}
    \begin{tabular}{|c|c|}
     \multicolumn{2}{l}{\textbf{PCB-I : Wave Generator}}\\
    \toprule
        Pin & Signal \\
    \midrule
        \multicolumn{2}{|l|}{P1}\\
    \midrule
    1 & Ground \\
    2 & Power Supply +10.5$\pm$1.5\\
    3 & Power Supply -4$\pm$1\\
    4 & Ground \\
    5 & Power Supply +4$\pm$1\\
    6 & Power Supply -10.5$\pm$1.5\\
    \midrule
        \multicolumn{2}{|l|}{P2}\\
    \midrule
    1 & Signal Out\\
    2 & Ground\\
    \bottomrule
\end{tabular}
\end{center}
\end{minipage}
\begin{minipage}{.48\textwidth}
\begin{center}
    \begin{tabular}{|c|c|}
     \multicolumn{2}{l}{\textbf{PCB-II : Amplifier}}\\
    \toprule
        Pin & Signal \\ 
    \midrule
    \multicolumn{2}{|l|}{P1}\\
    \midrule
    1 & Signal In\\
    2 & Ground\\
    \midrule
    \multicolumn{2}{|l|}{P2}\\
    \midrule
    1 & Power Supply +10.5$\pm$1.5\\
    2 & Audio Out\\
    3 & Ground\\
    4 & Audio Out\\
    5 & Power Supply -10.5$\pm$1.5\\
    \bottomrule
\end{tabular}
\end{center}
\end{minipage}
\newpage
\section{Fine-Tuning}
\vspace{-0.2cm}
\begin{enumerate}
    \item \textbf{Wave Generator} : The resistance values of multi-turn presets  R5, R13, R22, and R2 can be adjusted to achieve different damping time constant of the output wave. These are corresponding to frequencies 1100Hz, 790Hz, 537Hz, and 281Hz respectively. Users also have the flexibility to change R8, R17, R23, and R15 in an inversely proportional manner to vary the proportional constants of those frequencies on the final wave output.
    \vspace{-.3cm}
    \item \textbf{Amplifier} : The resistance value of the preset RP can be adjusted according to the power required to achieve different audio levels in the speaker output. Keeping the resistance values around 2K$\Omega$ is recommended for longer usage.
\end{enumerate}

\vspace{-1cm}
\section{Measurements}
\vspace{-.4cm}
\begin{figure}[h]
    \begin{minipage}{0.45\textwidth}
        \centering
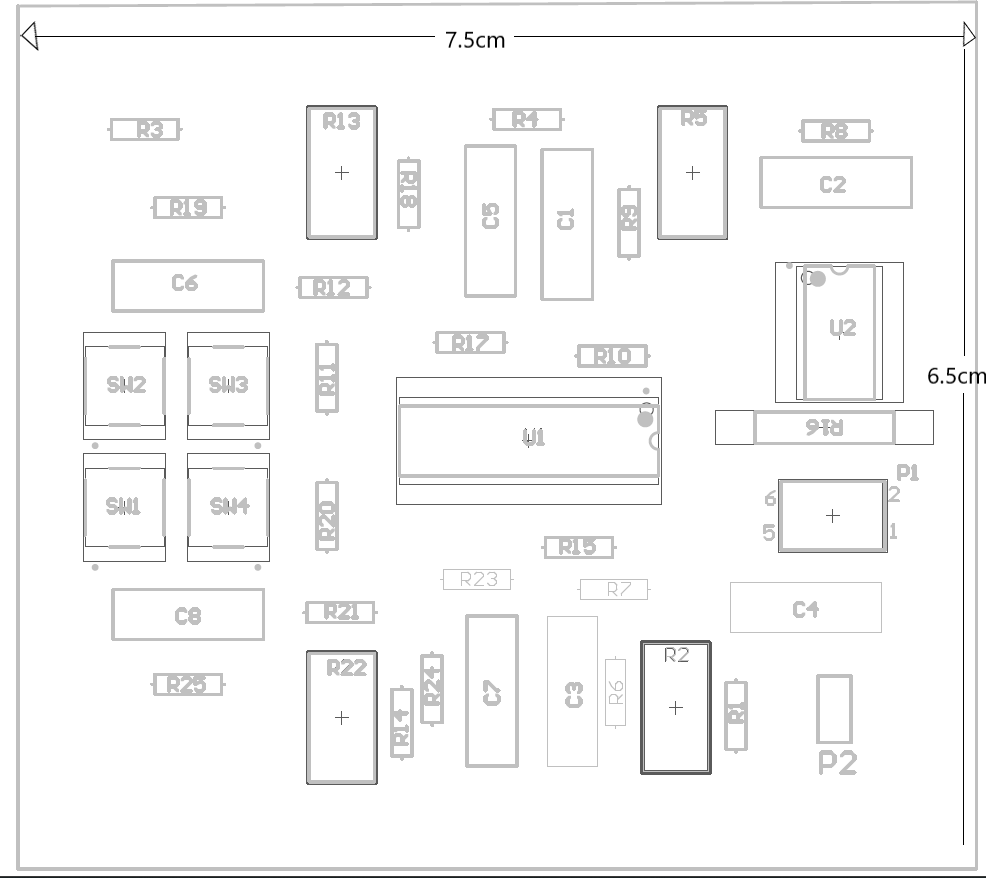
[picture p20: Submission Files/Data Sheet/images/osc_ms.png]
        
        \caption*{PCB-I : Wave Generator}
        \label{pcb_1}
    \end{minipage}
        \hfill
        \begin{minipage}{0.45\textwidth}
        \centering
        
        \caption*{PCB-II : Amplifier}
        \label{pcb_2}
    \end{minipage}
\end{figure}
\vspace{-1.3cm}
\section{Application Curves}
\vspace{-.2cm}
The output wave pattern(\ref{wave}) and its spectrum(\ref{spectrum}) at the end of wave generator are indicated in the following figures. The damping time constant can be elongated via the variable resistor attached to each oscillator.
\begin{figure}[h]
    \begin{minipage}{0.47\textwidth}
        \centering
        
        \caption{Final Wave Pattern}
        \label{wave}
    \end{minipage}
        \hfill
        \begin{minipage}{0.47\textwidth}
        \centering
        
        \caption{Frequency Spectrum}
        \label{spectrum}
    \end{minipage}
\end{figure}

The magnitude response(\ref{magnitude}) and phase response(\ref{phase}) of the amplifier are indicated below. The amplifier is suitable for frequencies ranging from 0Hz to 12kHz. This is visible from the facts that the overall gain is maintained at a constant value according to the volume control and the phase is maintained at -180$\degree$ in that range.
\begin{figure}[h]
    \begin{minipage}{0.47\textwidth}
        \centering
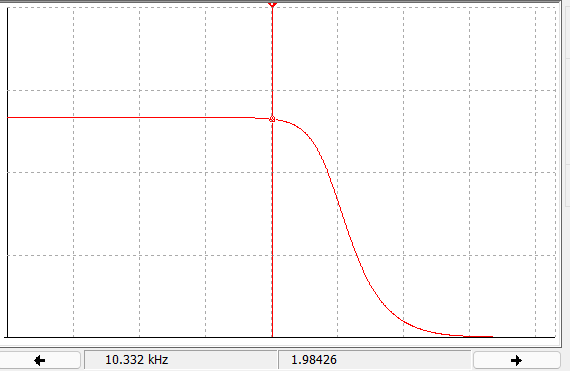
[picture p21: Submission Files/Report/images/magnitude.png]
        
        \caption{Magnitude}
        \label{magnitude}
    \end{minipage}
    \hfill
    \begin{minipage}{0.47\textwidth}
        \centering
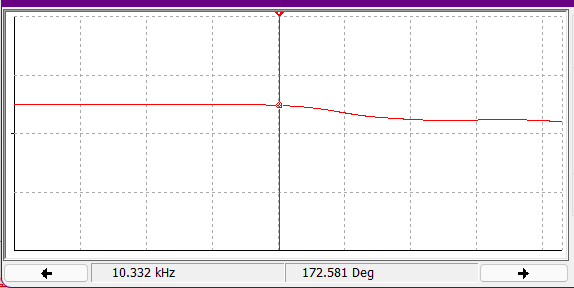
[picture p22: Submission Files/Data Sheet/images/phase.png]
        
        \caption{Phase}
        \label{phase}
    \end{minipage}
\end{figure}

\begin{figure}[p]
\begin{center}
\vspace{-4cm}
    
\end{center}
\end{figure}
\begin{figure}[p]
\begin{center}
\vspace{-5cm}
    
\end{center}
\end{figure}
\end{document}

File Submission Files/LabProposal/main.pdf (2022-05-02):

## Piano

Proposal : Group 22

## Description

The piano can be considered as a simple starting point of fusing music into electronics. The purpose of this project is to develop a piano with seven notes with only analog electronic circuits.

## Outcomes

Design a piano that can generate sounds of frequencies associated with all the seven notes which are sensible for the human ear. The piano sound must be amplified for the sake of making it audible clearly. It is expected that the sound to be smoothened with noise-free constraints to make it more enjoyable.

Skills

1. Hands-on experience with analog wave generation and wave addition.
2. Designing amplifier circuits from scratch which can handle higher frequencies.

Evaluation Criteria

1. Design: Neatness, and sustainability of the electronic circuit.
2. Smoothness and audible level of output.
3. The smoothness of sound during switching between notes.

## Additional Notes

1. Members are not allowed to use any kind of IC, Timers, or op-amps in the design of the project.
2. Members are expected to have proper noise-cancelling strategies to make the sound enjoyable.
3. Having a proper sound controlling mechanism to switch between sounds is considered a plus.
4. Members are expected to implement techniques of pure wave generation and wave addition to achieve these requirements.

1

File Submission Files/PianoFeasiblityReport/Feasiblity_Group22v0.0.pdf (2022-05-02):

∗Feasiblity Report → Group : 22

# The Piano

## Literature Review

The Analog signal generator design is a common project around the senior years of EN2090 module from the ENTC department. It engaged the circuit design of the Wien bridge oscillator, as a low-frequency sine wave generator. It can be utilized to produce sine waves in the audio frequency range. Analog electronic musical instrument designs available in the market engaged the concept of modulation with a sine wave to get a sudden change in frequency output. This strategy can be mimicked to implement a pedal design that can deliver an experience of sudden change in sound pitch.
Old speakers used an audio equalizer using RLC circuit to lower or boost certain frequency ranges specifically. This can be utilized in our piano to change the softness of the generated sound. In earlier days, most of the sound devices available in the market starting from simple analog radio up to studio speakers engaged voltage amplifiers to amplify the audio signal to a sustainable level. The circuit design of amplifiers also had the capability of removing dc offset which is a danger to the speaker.

## Block Diagram

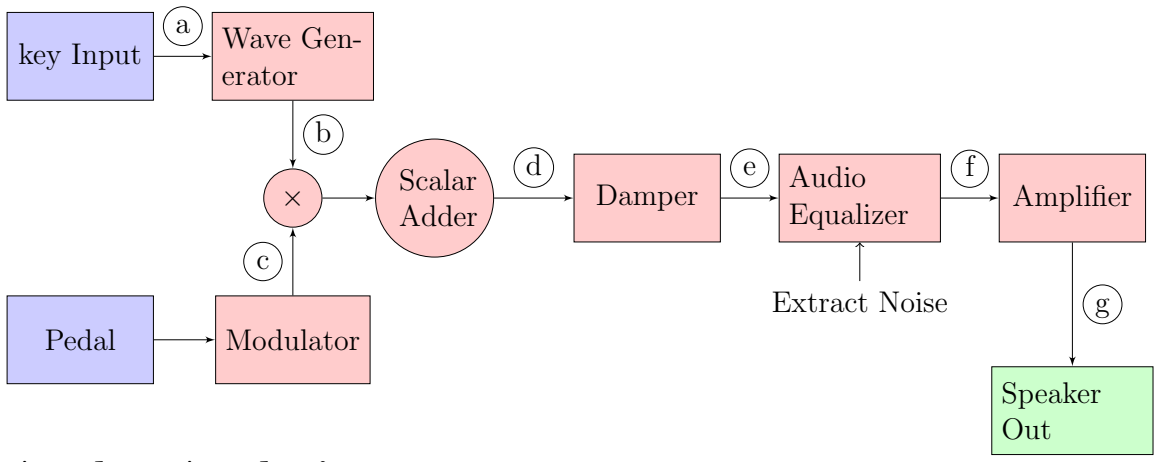
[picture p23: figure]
key Input; Wave Gen-; erator; Scalar Adder; Pedal; Modulator; Damper; Audio; Equalizer; Extract Noise; Amplifier; Speaker Out

## Analog Analysis

a : The effect resistor values in frequeny of the wave generation.

b : Pureness of sine waves generated with fundamental and over tone frequencies.

c : Modulation with a sine wave to get a higher octave.

d : Addition of the harmonic components according to the amplitude ratio.

1

e : Analyzation of exponential decay of audio signal.

f : Analyzing softness of sound by scaling different frequecy ranges.

e : Anlysing the output audio signal with different amplifiaction factor.

## Methodology

Analyzation of Piano Notes
Analyzing the frequency spectrum of sounds from each note of the piano, as to mimic the exact spectrum through the addition of sine waves.

Wave Generation
We have decided to implement the Wein Bridge oscillator circuit to generate sine waves spans in the audio frequency range. The circuit allows modification of frequencies by interchanging values of resistance used. This character can be utilized to map the keys with corresponding wave generation.

Damping of Audio Signals
As a step of mimicing the sound from Piano we need to decay the audio signal in an exponential manner. As of now, it is decided to implement the strategy used in envelope detector as to get an exponential decay in sound.

Amplification
As a step of getting audible sound from the piano, we decided to implement a non inverter amplifier circuit using operational amplifier.

Modulation
Inorder to observe sudden change in octave on the pedal press, it is decided to implement a modulator. Modulator design consist of a simple wave generator of required frequency and wave Multiplication.

Audio Equalizer
Audio Equalizer softens the sound wave to give a pleasurable experience from the piano. The design of the equalizer consists of frequency filters. It separates the sound signal under frequency categories and boosts or lowers its amplitude as per preference.

## References

1. Synthesizing Frequency of Notes → https://web.eecs.utk.edu/ hqi/ece505/project/proj1.pdf
2. Wave Generation → https : //en.wikipedia.org/wiki/W ien bridge oscillator/ https://www.homemade-circuits.com/simple-sine-wave-generator-circuits/
3. Mathematics of Sound → https://www.ams.jhu.edu/dan-mathofmusic/sound-waves/
4. Similar Project with High Scope → http://www.jiisuki.net/reports/howto-buildanalog-synth.pdf
5. Audio Equalizer → https://circuitdigest.com/electronic-circuits/audio-equalizertone-control-circuit-with-bass-treble-and-mid-frequency-control

2

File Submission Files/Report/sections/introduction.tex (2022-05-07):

\section{Introduction}
Music is one of the key things to please people and it’s based on musical notes. It is so wonderful to observe such notes can be generated by combining sinusoidal signals.
\par
In this device sound of the middle octave, C is mimicked by synthesizing signals. For this purpose, four wien-bridge oscillators have been used to generate sinusoidal waveforms relevant to the major harmonics of the C note. Then these signals are added by a scaling adder and amplified using a Class AB amplifier. A speaker(8$\Omega$ preferred) ranging around 3W could be used with the pinout to observe the sound output.
\par
The volume of the speaker and the noise level can be adjusted as the user desires. A complete electronic piano can be implemented by combining such modules and changing the essentials accordingly to generate different notes. This report will elaborate on the experiences and ideas behind the design process.

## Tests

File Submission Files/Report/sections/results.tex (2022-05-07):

\section{Results}
The evaluation of the model happened in three stages. The first part completely relied on simulation results. The second was the physical simulation of separate modules independently on the breadboard. Finally, the complete prototype was built and tested.
\par
The requirements that needed to be met, and the method utilized to test whether they have been met are as follows:

\begin{figure}[h]
    \resizebox{\columnwidth}{!}{
        \begin{tabular}{|c|c|c|}
            \toprule
            Design              & \multirow{2}{*}{Target Value} & \multirow{2}{*}{Testing Method}          \\
            Requirement         &                               &                                          \\
            \midrule\midrule
            Spectrum            & Specified Amplitude Ratios    & \multirow{3}{*}{Stimulation}             \\
            \cmidrule(lr){1-2}
            Wave pattern        & Exponential-Decay             &                                          \\
            \cmidrule(lr){1-2}
            Power Efficiency    & 75\%                          &                                          \\
            \midrule
            Speakers            & 4$\Omega$-16$\Omega$ \& 1W-5W & Prototype                                \\
            \midrule
            Quality \& Loudness & 40dB-75dB                     & \multirow{2}{*}{Stimulation/ Prototype } \\
            \cmidrule(lr){1-2}
            Datasheet           & parameters                    &                                          \\
            \bottomrule
        \end{tabular}}
\end{figure}
\subsection{Simulation}
\subsubsection*{Wave Generator}
The outputs of oscillators are very stable although a slight variation in the frequencies($\pm 3$) was observed. The following figures illustrate the observed decay pattern and stable waveform from an oscillator.
\begin{figure}[h]
    \begin{subfigure}{.48\columnwidth}
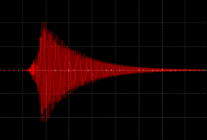
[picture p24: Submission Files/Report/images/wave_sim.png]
        
        \caption*{Envelope Pattern}
    \end{subfigure}
    \begin{subfigure}{.48\columnwidth}
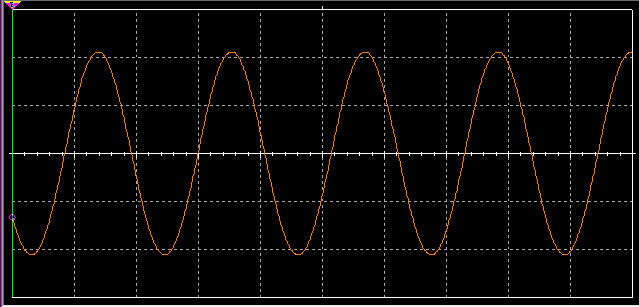
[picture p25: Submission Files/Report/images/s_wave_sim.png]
        
        \caption*{Wave Pattern}
    \end{subfigure}
\end{figure}

The output of the scalar adder looked similar to the original waveform and the spectrums were closely matched. Somehow at the simulation stage, sound outputs failed to match. Expected and observed wave characteristics as follows:
\begin{figure}[h]
    
\end{figure}
\\
These stages are operated at low power and the oscillations are normally in a damped state. This allows keeping the overall output of the wave generator to be in a normally-off state which is crucial for power efficiency.
\subsubsection*{Amplifier}
Although the wave synthesis process is limited to frequencies lower than 5kHz, it is initially planned to implement an amplifier that has a constant gain throughout the full audible range(up to 20kHz). From the observations, the model was limited to 12kHz which is expected due to imperfections in transistor behaviors.
\begin{figure}[h]
    \begin{subfigure}{.48\columnwidth}
        
        \caption*{Voltage Gain}
    \end{subfigure}
    \begin{subfigure}{.48\columnwidth}
        
        \caption*{Phase}
    \end{subfigure}
\end{figure}
\\
From the simulation, it was confirmed that the feedback resistance gives linear control over the gain of the amplifier.
\begin{enumerate}
    \item \textbf{Input Resistance} : \textbf{28.2k$\Omega$}\\The input resistance was determined by using the multimeter tool to measure the current drawn from the source and dividing the source voltage by the measured value.
    \item \textbf{Output Impedance} : \textbf{1.9$\Omega$}\\The output impedance was calculated by using voltmeter tool and constant current source. The input was sort-circuited and constant current source applied in the output. Then the voltmeter reading in the current source was measured.
          $$R_{out}=\frac{V_{read}}{I_{source}}$$
    \item \textbf{Bandwidth} : \textbf{200Hz-12kHz}\\Bandwidth was determined using the bode-plot of the amplifier. The region where gain stays constant is only considered.
    \item \textbf{Gain}(8$\Omega$) : \textbf{50dB-70dB}\\The gain was determined using the wattmeter tool between the input source and speaker input.
    \item \textbf{Power Efficiency} : \textbf{69\%}\\
          $$\eta=\frac{P_L}{P_S}\times 100\%$$
    \item \textbf{Safety Measurements :} \\
          The maximum current path was observed to conduct 600mA in the worst case. This was considered in the maximum power calculations and component selections.
\end{enumerate}

\subsection{Circuit Blocks}
\subsubsection*{Wave Generator}
Noise-free stable wave pattern is observed at each oscillator. The measured frequencies vary in the range of 10Hz as expected due to the imperfection in resistance selection. Although the wave pattern observed had  clipping effect it was observed that they could be eliminated by fine-tuning.
\begin{figure}[h]
    \begin{subfigure}{.48\columnwidth}
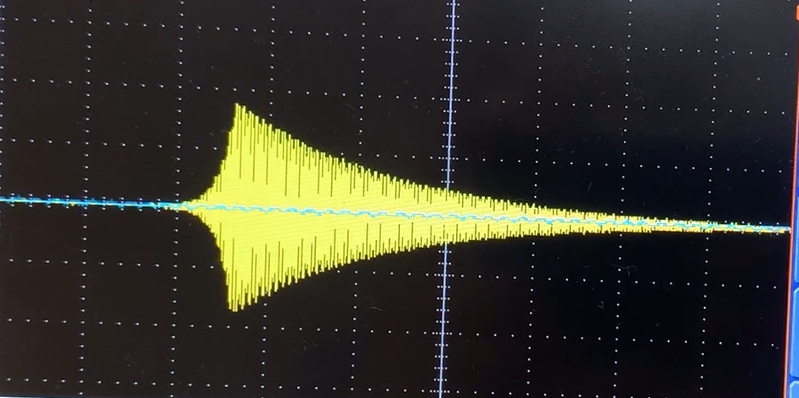
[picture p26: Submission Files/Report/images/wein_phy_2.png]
        
        \caption*{Envelope Pattern}
    \end{subfigure}
    \begin{subfigure}{.48\columnwidth}
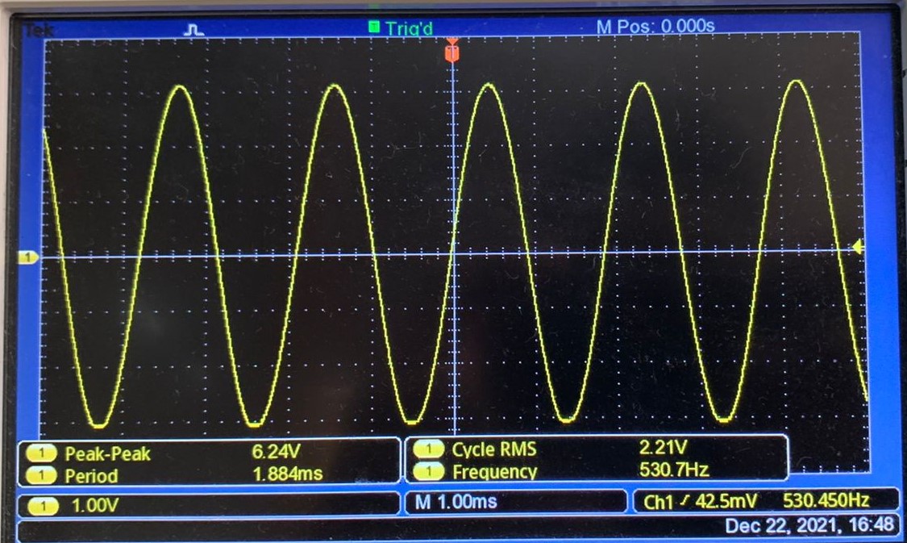
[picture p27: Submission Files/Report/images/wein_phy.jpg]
        
        \caption*{Wave Pattern}
    \end{subfigure}
\end{figure}

\subsubsection*{Amplifier}
The parameters measured were varied with simulation results.
\begin{enumerate}
    \item \textbf{Input Resistance} : \textbf{43M$\Omega$}\\The input impedance was determined by using a digital multimeter to measure the current being drawn from the input for an audio input of 0.1mA (peak to peak), with the output open-circuited.
    \item \textbf{Output Impedance} : \textbf{10$\Omega$}\\Output impedance was measured using the voltmeter, from the open circuit reading in the output terminal ($V_O$) and the reading in the 8$\Omega$ load ($V_L$).
          $$R_{out}=R_L\times\frac{V_L}{V_O}$$
    \item \textbf{Bandwidth} : \textbf{200Hz-12kHz}\\Bandwidth was determined using bode-plot of the amplifier. The region where gain stays constant was only considered.
    \item \textbf{Power Efficiency} : \textbf{63\%}\\
          Efficiency was determined by inspecting the supply and speaker inputs.
    \item \textbf{Maximum Current} : \textbf{0.4A}
\end{enumerate}
The performance of the amplifier with song output from a mobile phone is also inspected at this stage. The results are as follows.
\begin{figure}[h]
    \centering
    
    \caption*{\textbf{Song Wave} : Input - Yellow \& Output - Blue}
\end{figure}

\subsection{Integrated-Circuit}
The wave generator is cascaded with the amplifier to create the final prototype of the design. The sound output of the completed circuit was observed very familiarly with the c-wave of the piano. The waveforms of the original wave and finely tuned wave output are as follows:
\begin{figure}[h]
    \begin{subfigure}{.48\columnwidth}
    \centering
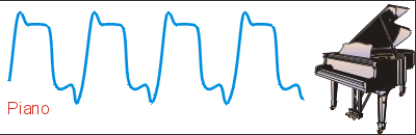
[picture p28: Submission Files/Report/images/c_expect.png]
    
    \caption*{Original Wave}
    \end{subfigure}
    \begin{subfigure}{.48\columnwidth}
        \centering
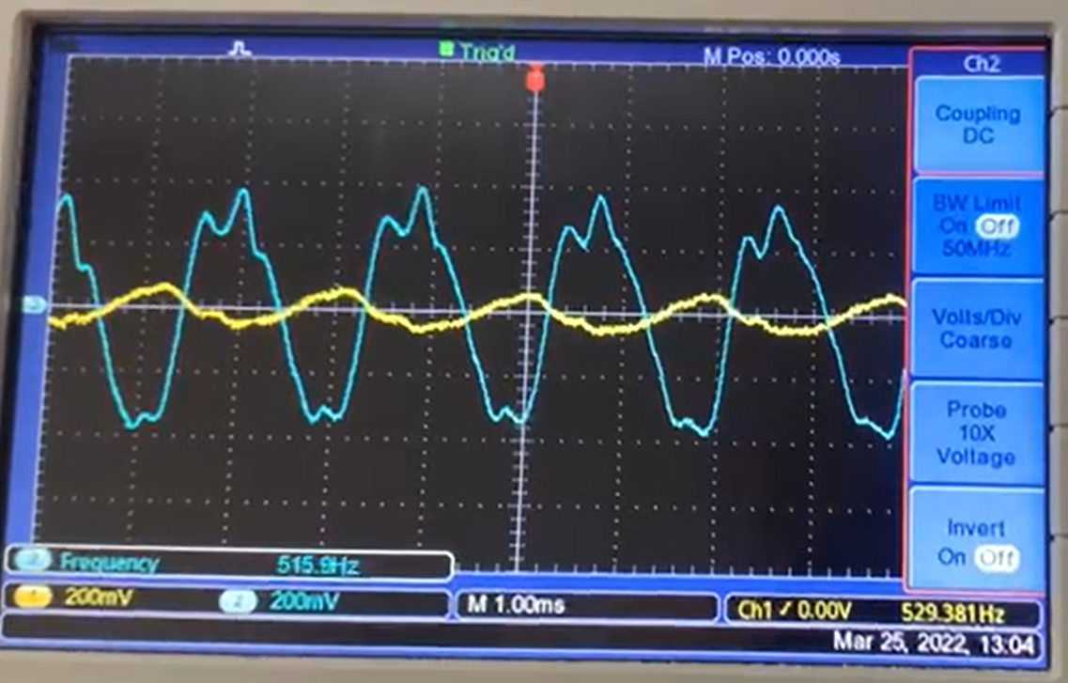
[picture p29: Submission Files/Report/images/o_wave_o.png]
        
        \caption*{Tuned Output}
    \end{subfigure}
    \newline
    \begin{subfigure}{.48\columnwidth}
        \centering
    
    \caption*{Original Envelope}
\end{subfigure}
\begin{subfigure}{.48\columnwidth}
    \centering
    
    \caption*{Observation}
\end{subfigure}
\end{figure}
\\
Although a small elongation was observed at the start of oscillation this could also be controlled by parallel resistance that is responsible for the start of the oscillation. We suspected this behavior is due to an increase in impedance imposed by tracks.

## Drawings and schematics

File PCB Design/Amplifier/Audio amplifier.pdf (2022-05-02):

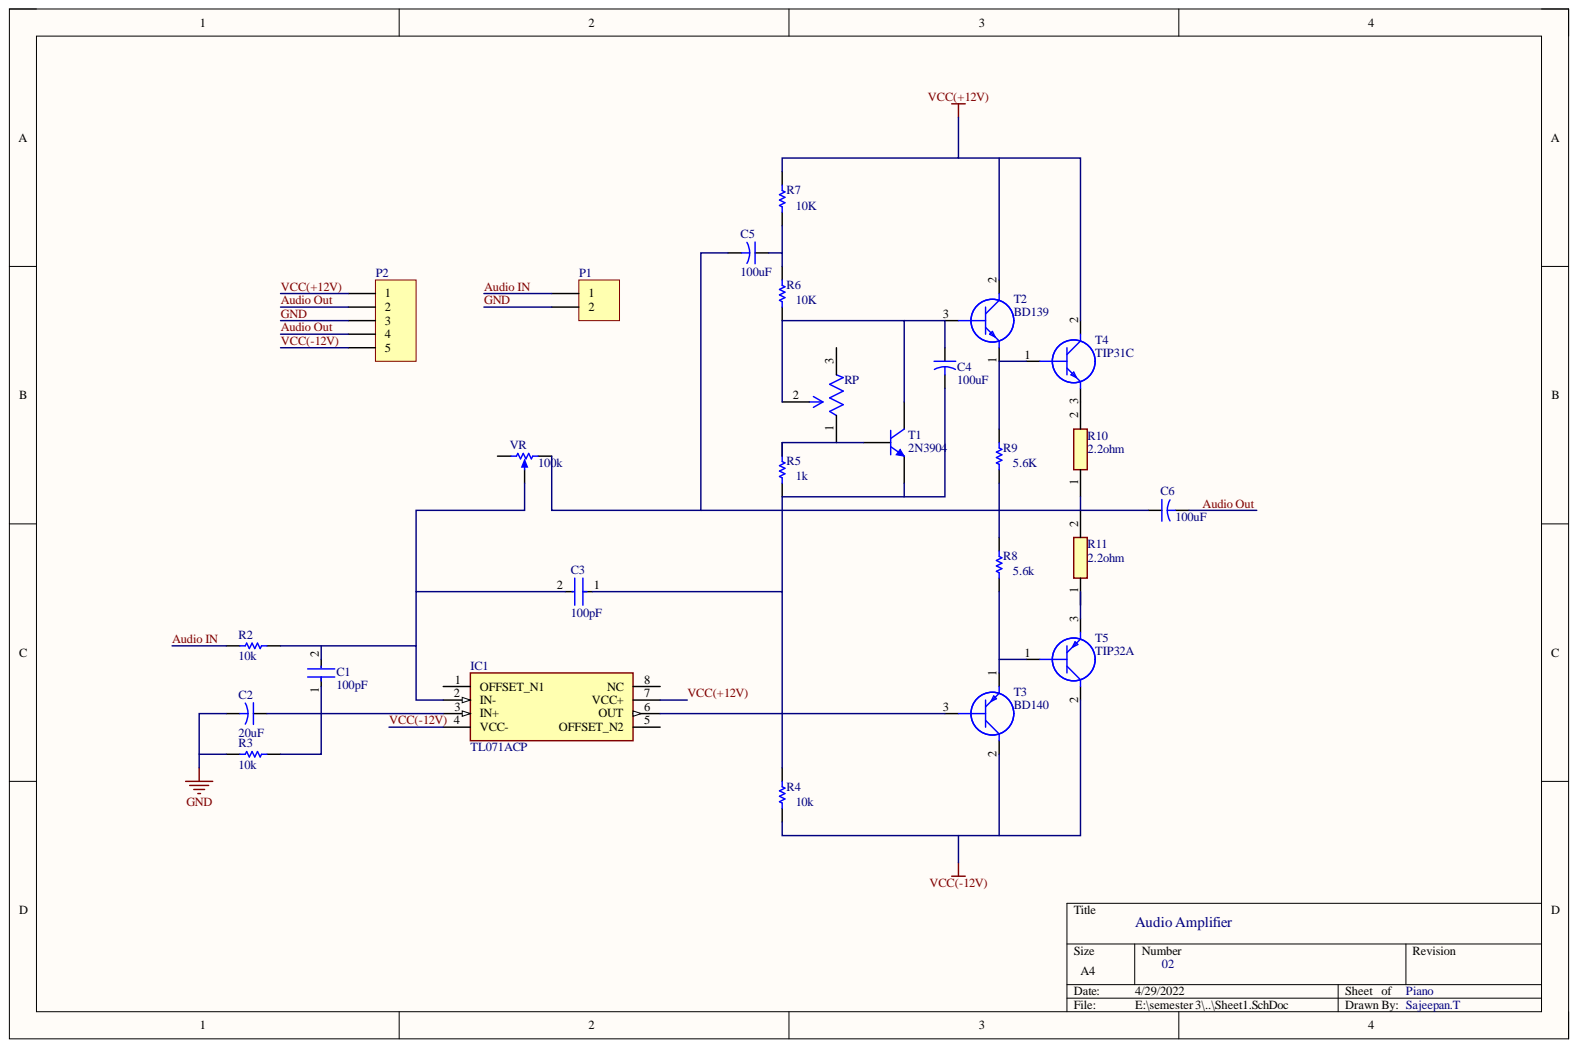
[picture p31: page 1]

VC C -OF F | N C VC C +

Siz e A4 | Numb e r 02 | R evisio n

Da te : 4/29/202 2 | She et of Pia n o
File : E:\semeste r 3\. .\She et1. S c hD o c | Dr awn By: S aje e p an . T

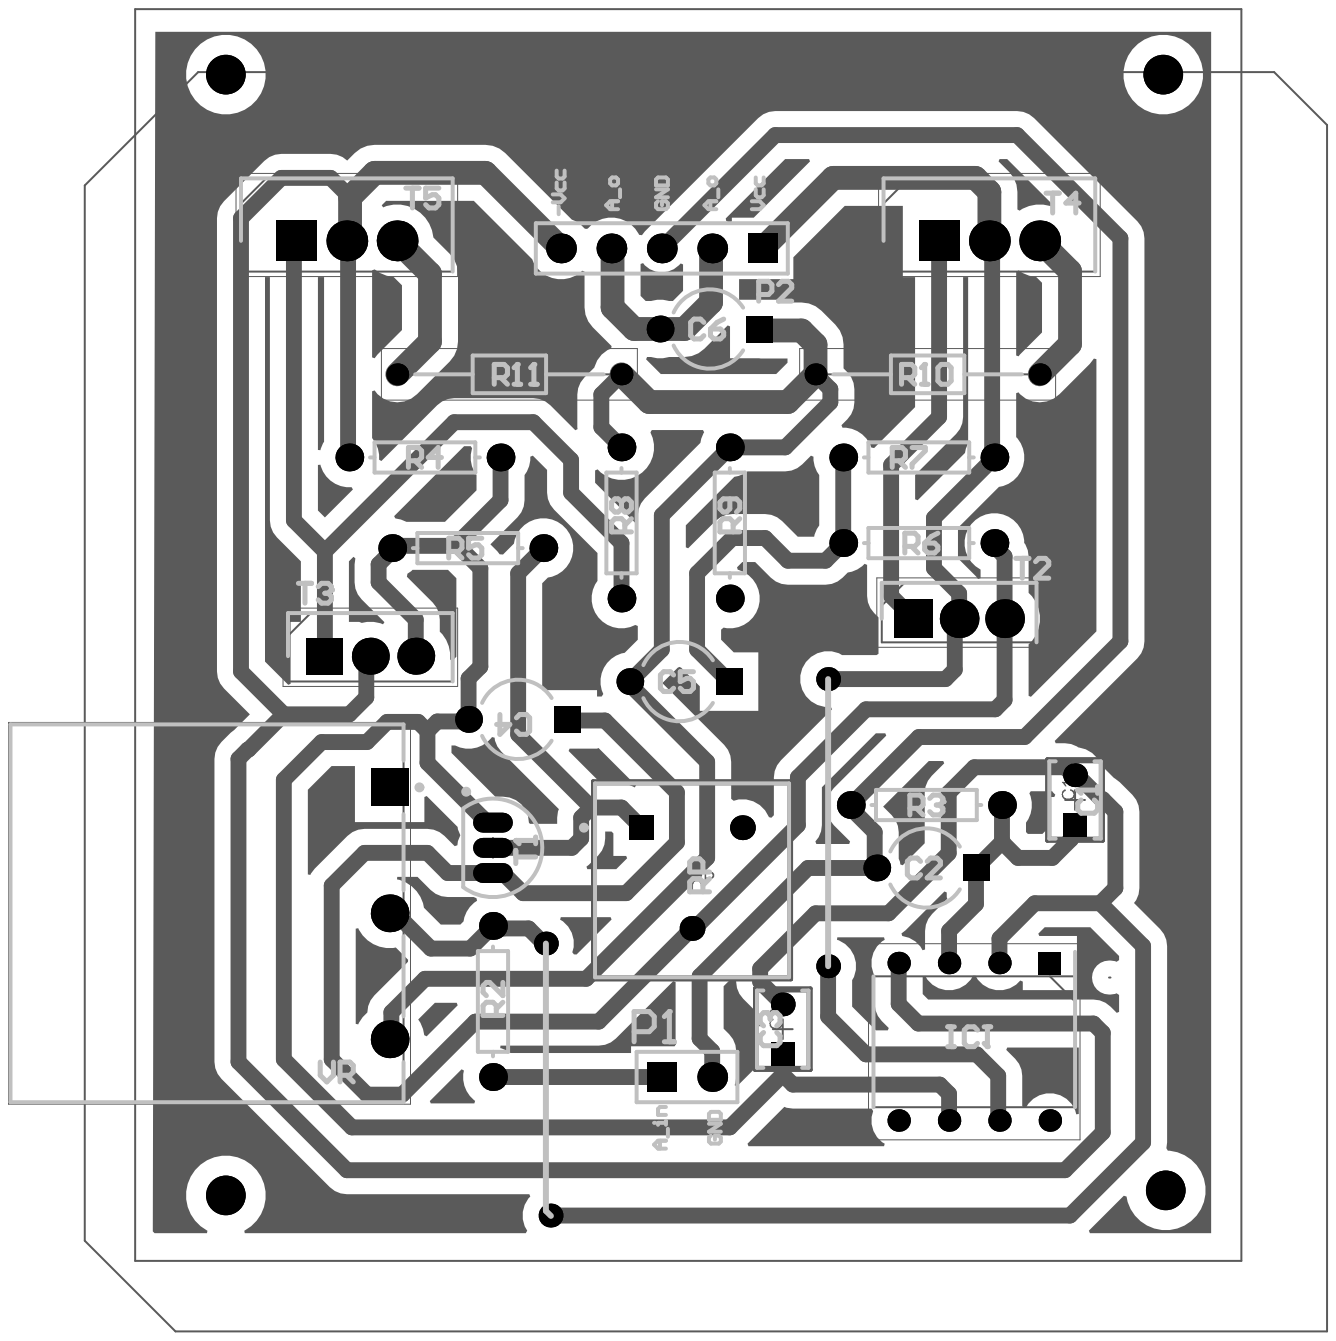
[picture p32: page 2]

Comment | Description | Designator | Footprint | LibRef | Quantity
100pF | CAP CER 100PF 100V CCG THRUHOLE | C1, C3 | FP-RHS0DG-MFG | CMP-06035-000016-1 | 2
Cap2 | Capacitor | C2, C4, C5, C6 | CAPR5-4X5 | Cap2 | 4
TL071ACP | Integrated Circuit | IC1 | DIP794W53P254L959 H508Q8N | TL071ACP | 1
Header 2 | Header, 2-Pin | P1 | HDR1X2 | Header 2 | 1
Header 5 | Header, 5-Pin | P2 | HDR1X5 | Header 5 | 1
Res1 | Resistor | R2, R3, R4, R5, R6, R7, R8, R9 | AXIAL-0.3 | Res1 | 8
2.2ohm | Resistor | R10, R11 | RESAD1130W50L370D 190 | MFF04FF6800A5 | 2
3386F-1-303LF | TRIMMER 30K OHM 0.5W PC PIN TOP | RP | FP-3386F-MFG | CMP-07234-000018-1 | 1
2N3904 | NPN General Purpose Amplifier | T1 | TO-92A | 2N3904 | 1
BD139 | Transistor BJT NPN | T2 | TO229P300X760X136 4-3P | BD139 | 1
BD140 | Transistor BJT PNP | T3 | TO229P345X800X146 0-3P | BD14010STU | 1
TIP31C | Transistor BJT NPN | T4 | TO254P470X1016X20 19-3P | TIP31C | 1
TIP32A | Transistor BJT PNP | T5 | TO254P470X1016X20 19-3P | TIP32A | 1
100k | Diameter Panel Control, 10 KOhm, +/-10%, 2 W, -1 to 125 degC, 3-Pin THD, RoHS, Bulk | VR | BOUR-3852A-282-103AL-3_V | CMP-2000-05079-1 | 1

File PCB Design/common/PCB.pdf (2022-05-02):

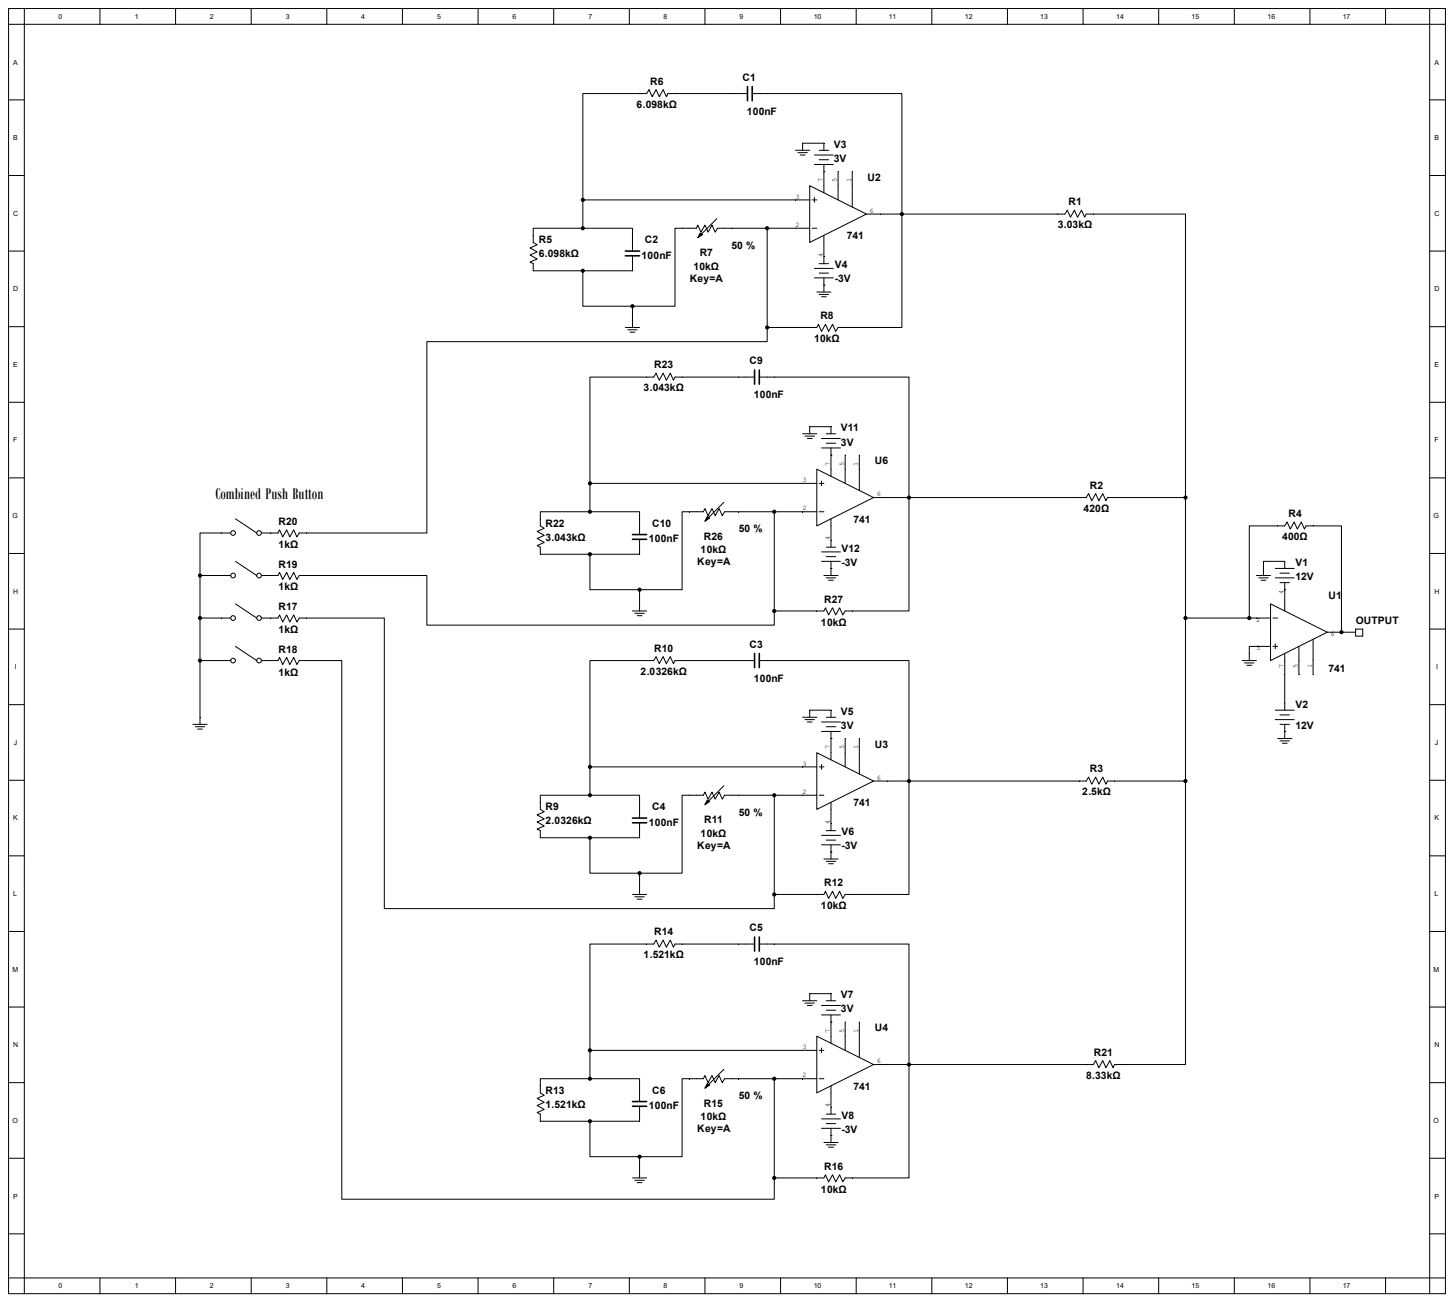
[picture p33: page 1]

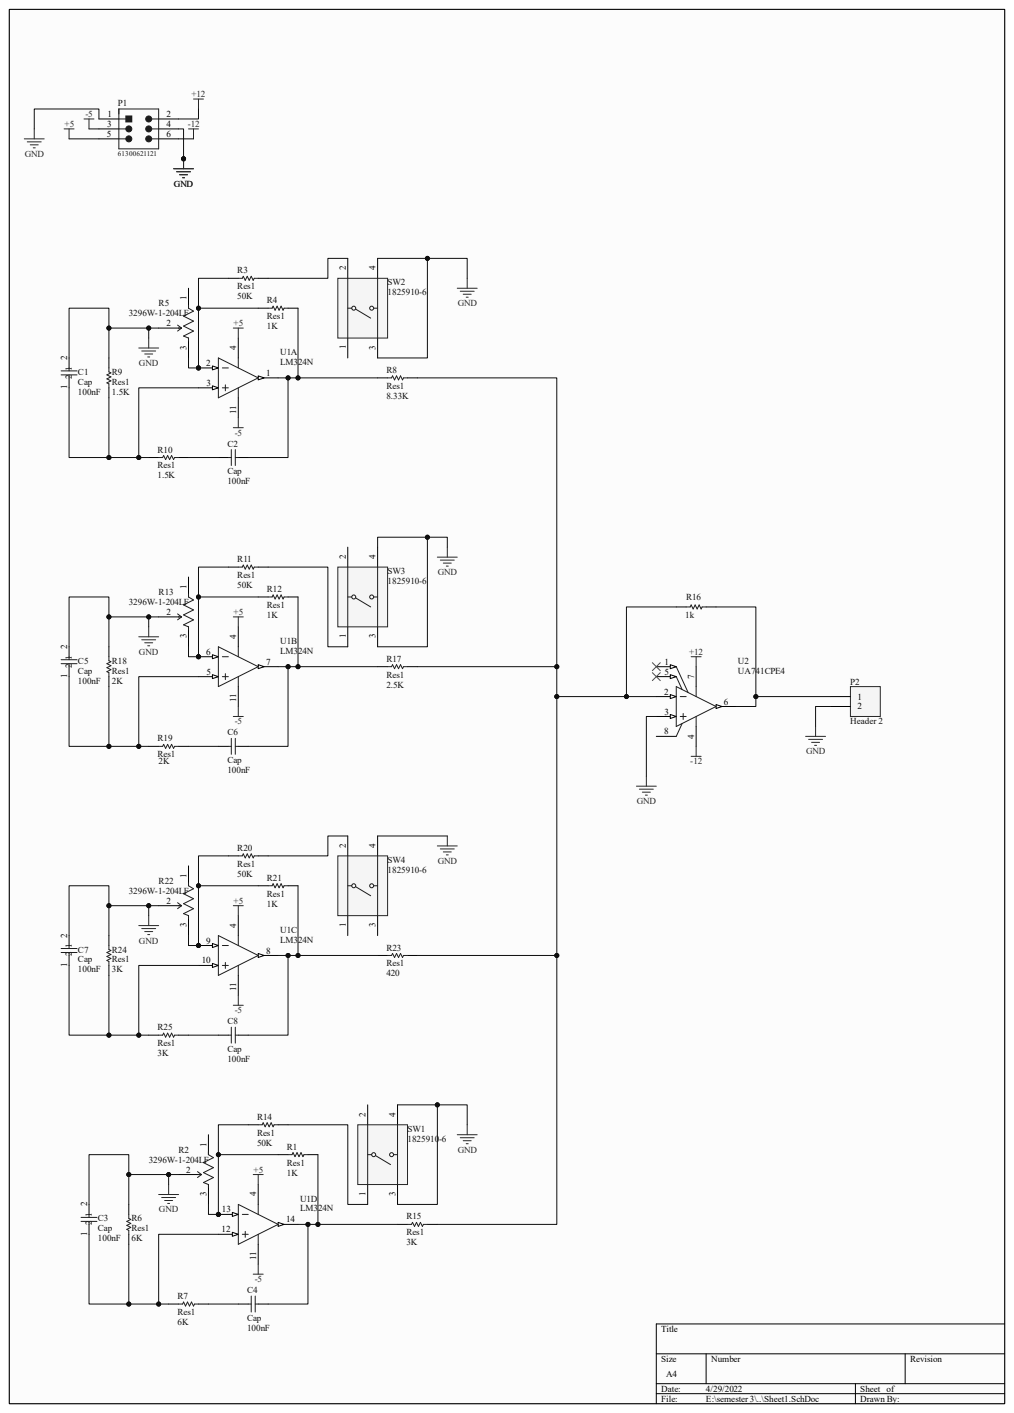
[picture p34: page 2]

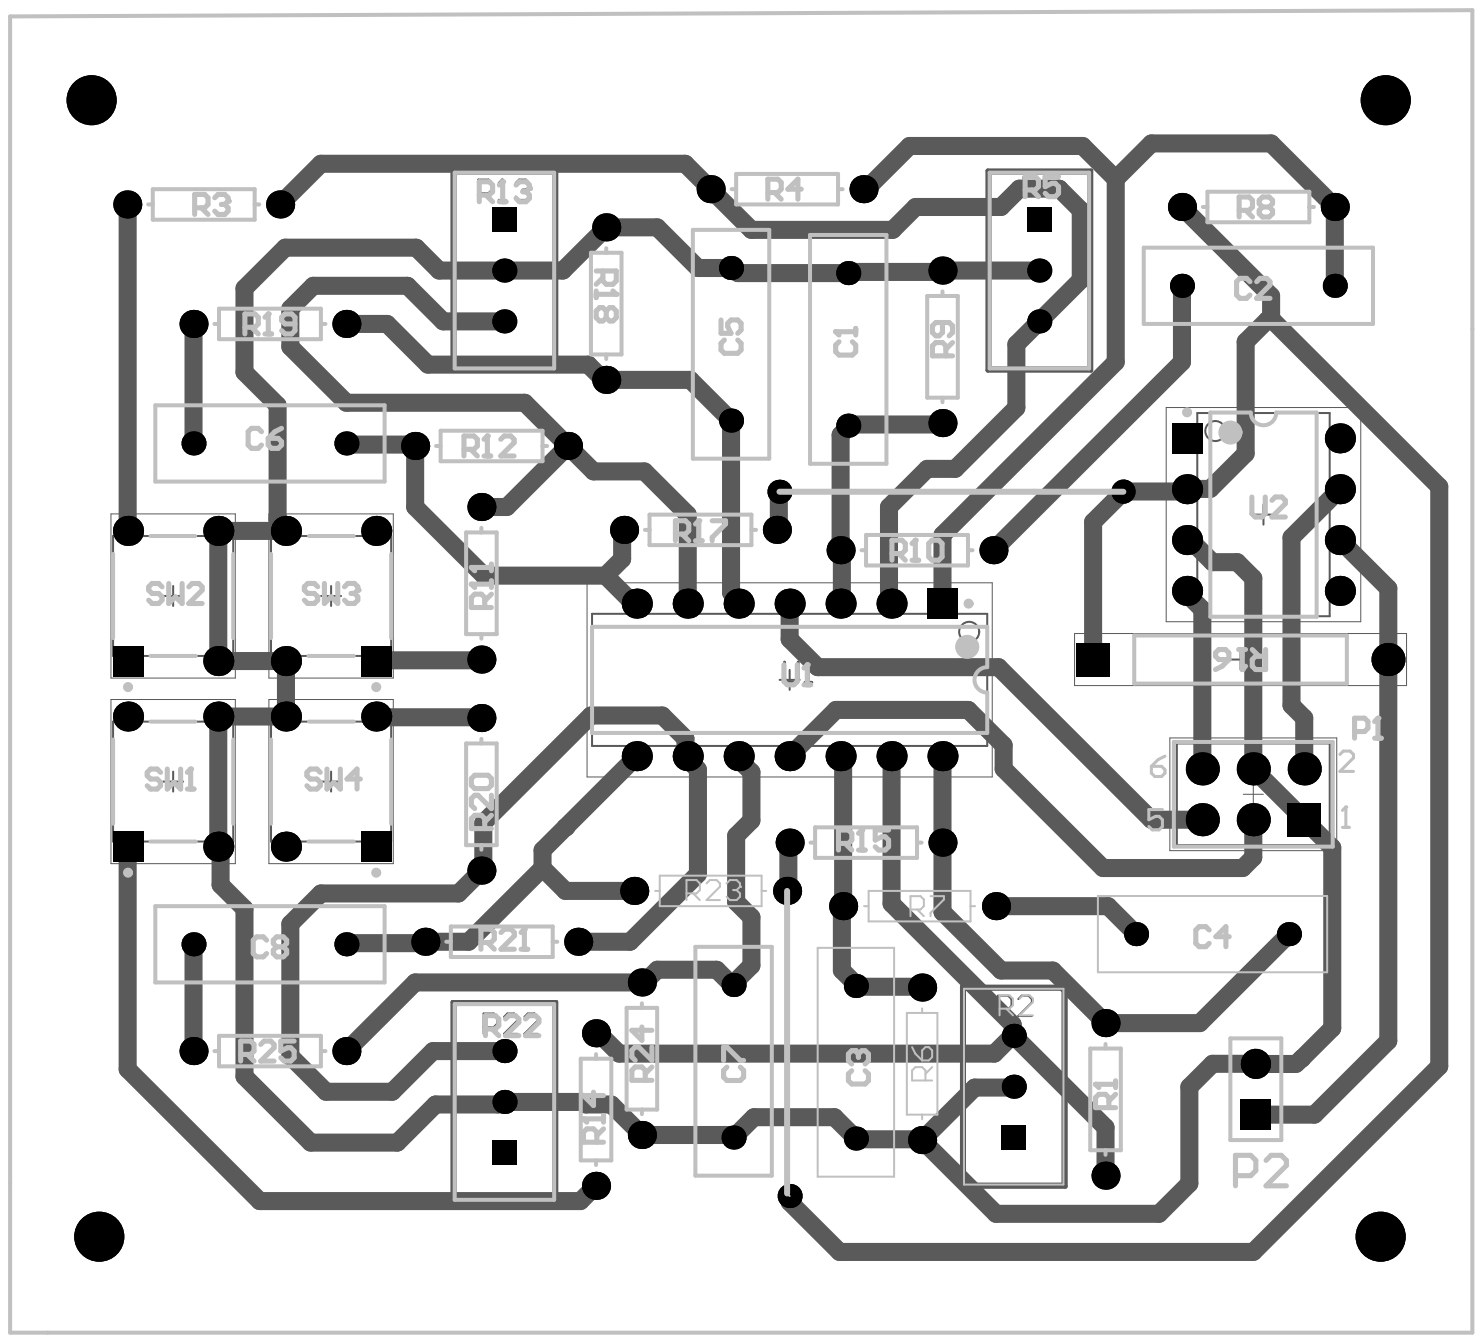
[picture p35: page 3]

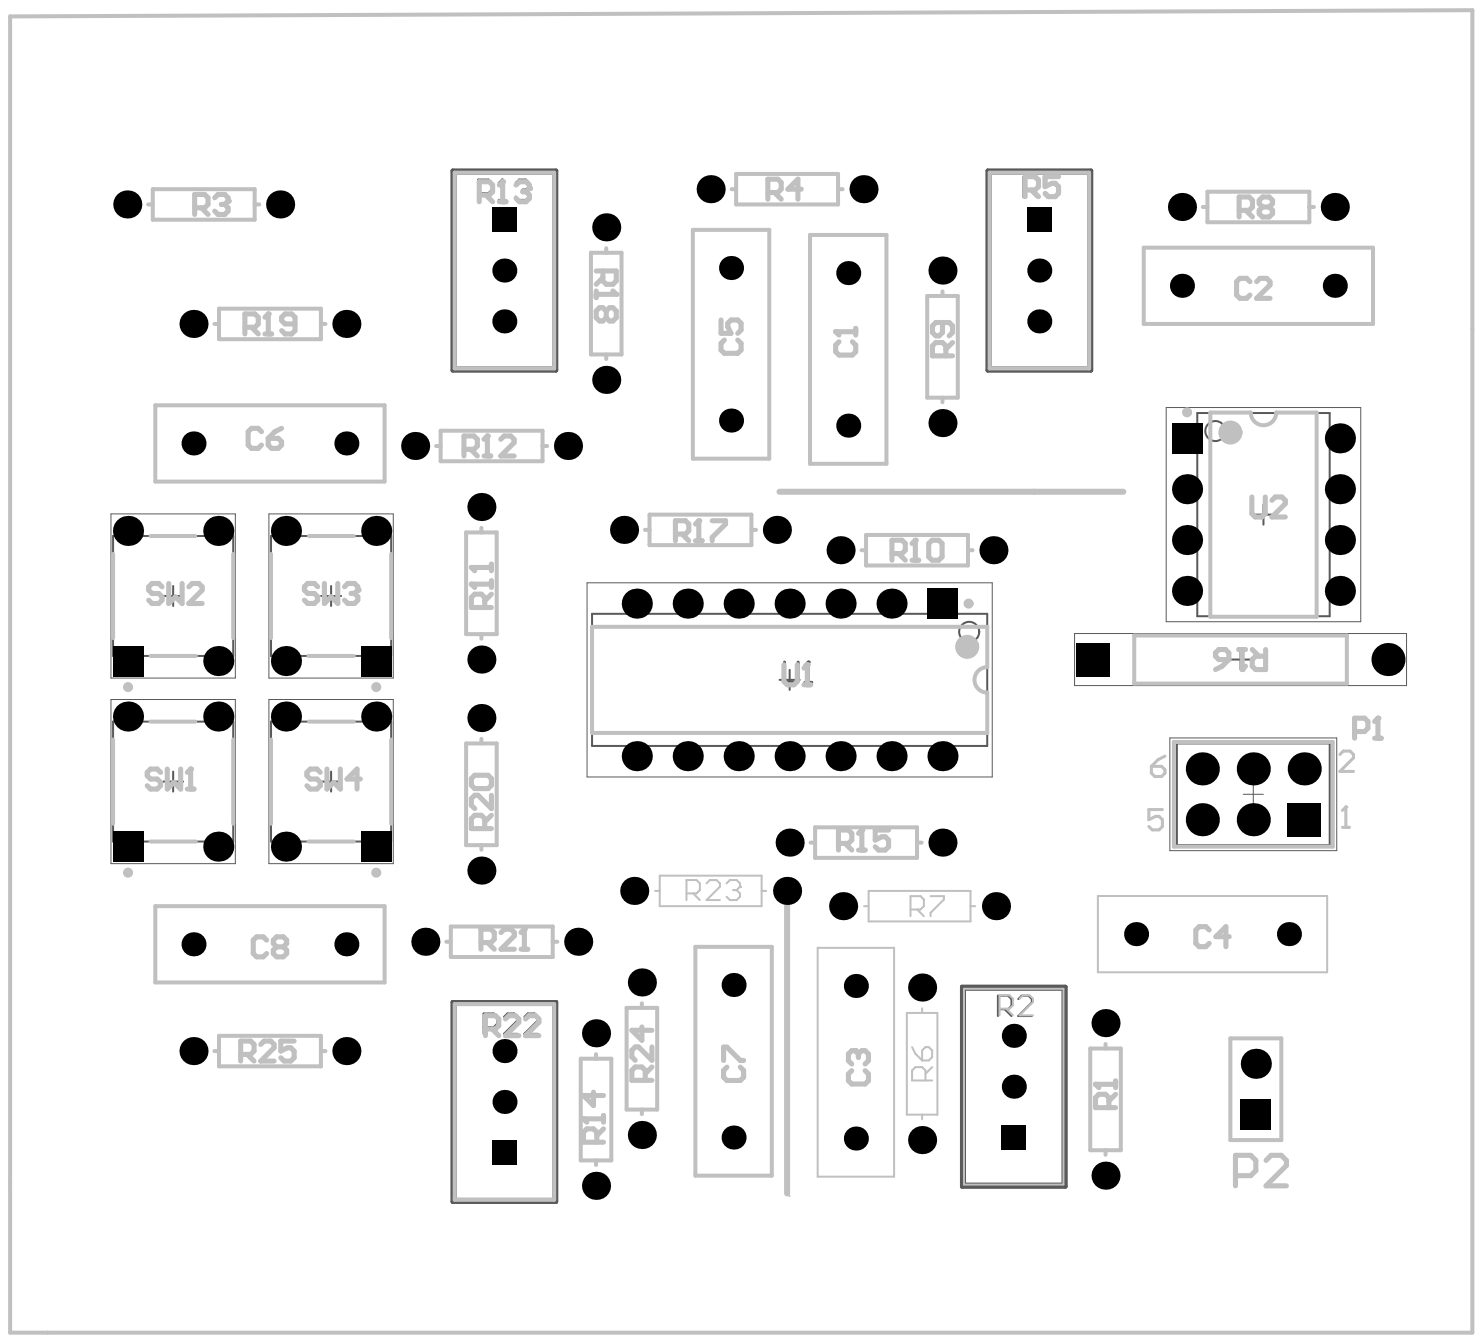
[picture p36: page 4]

12V

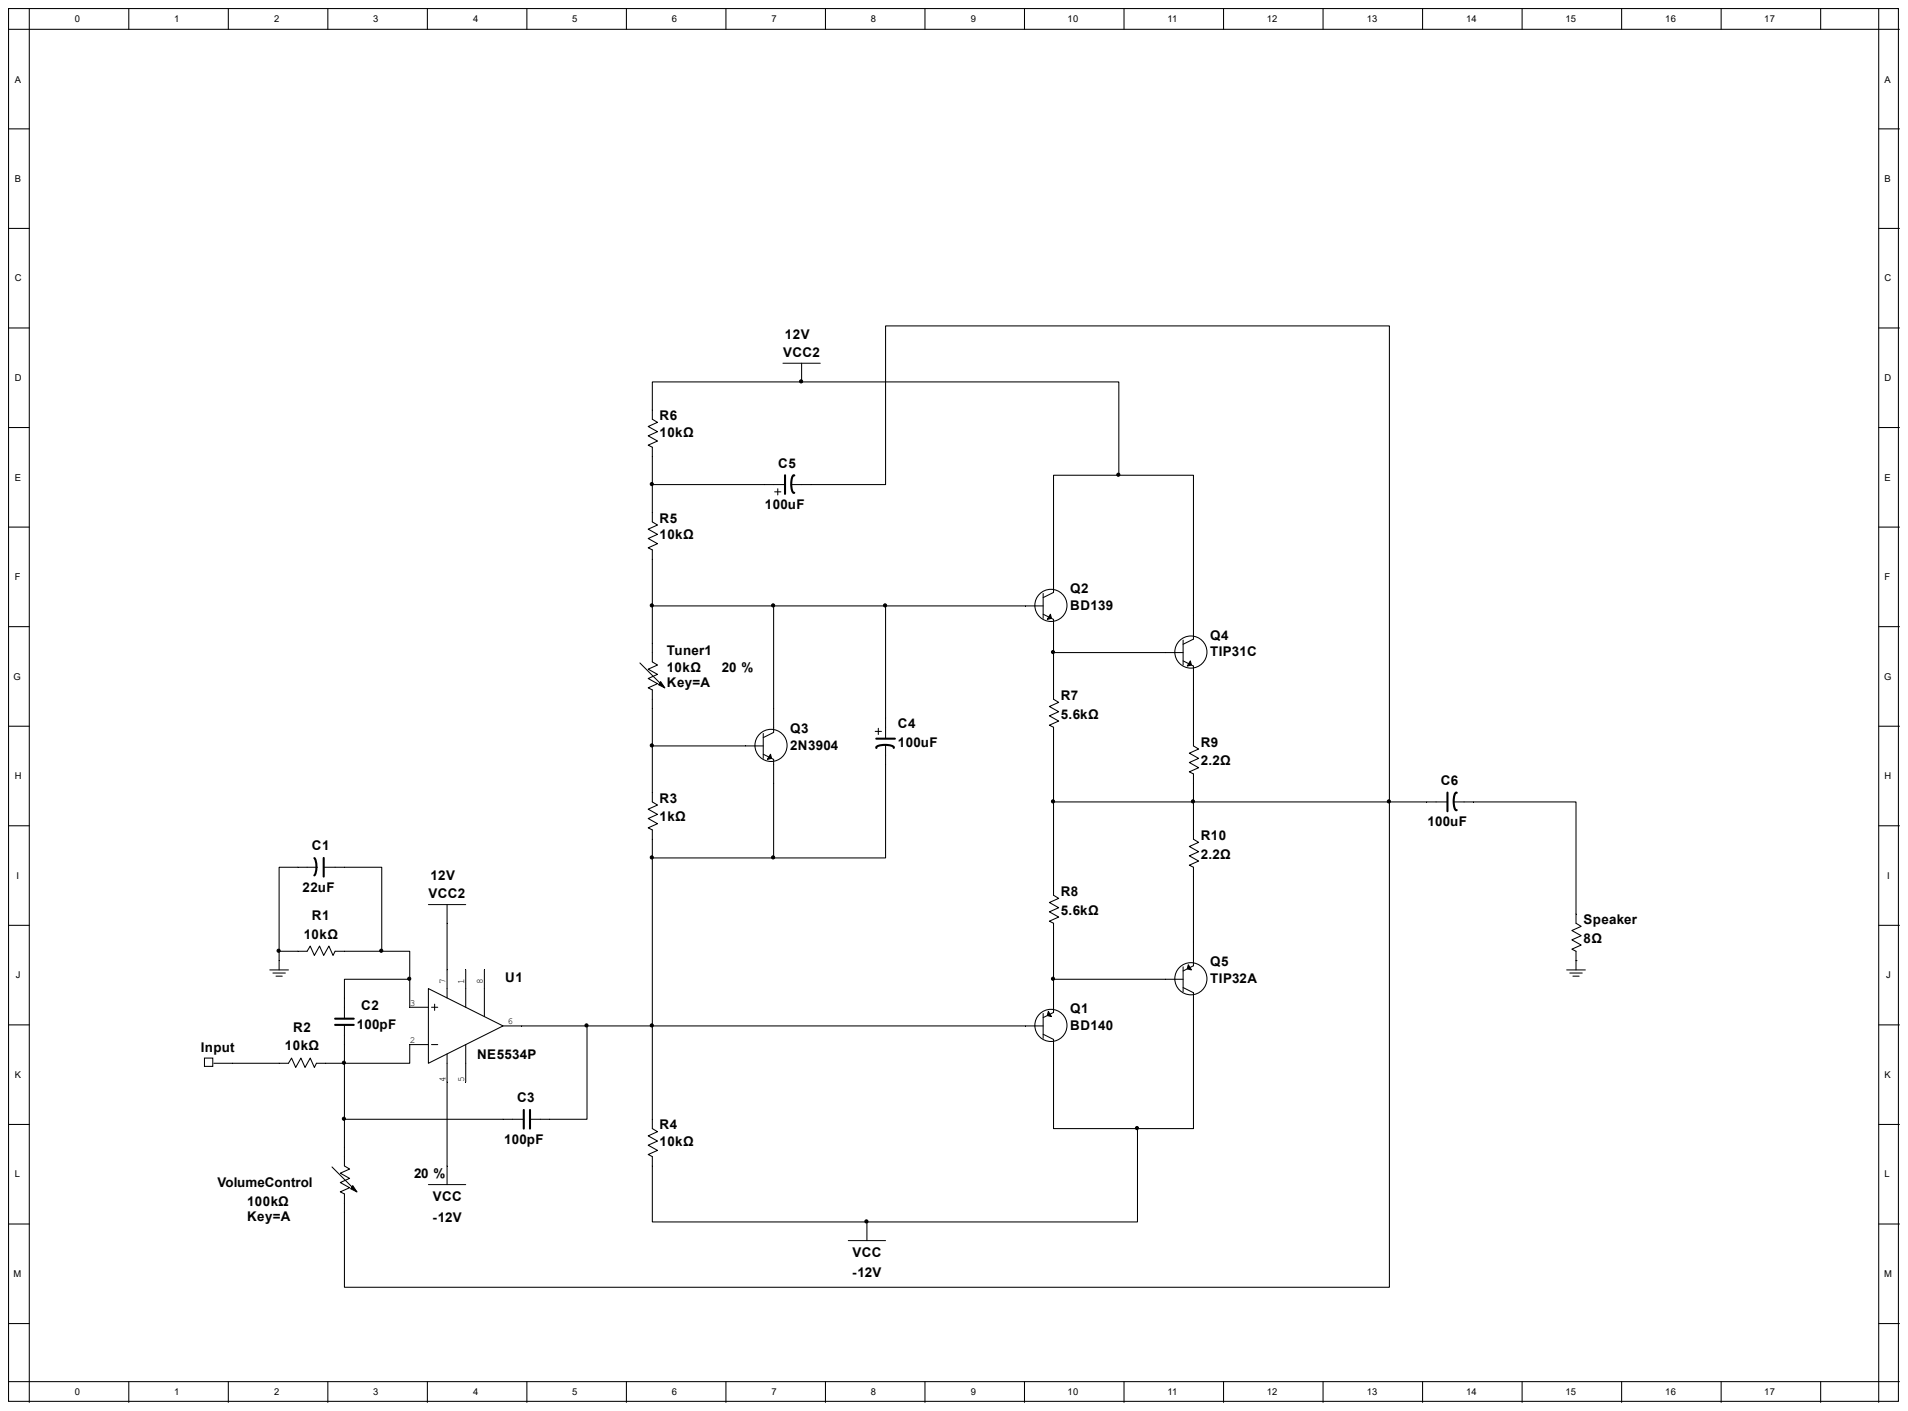
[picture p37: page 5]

1

2

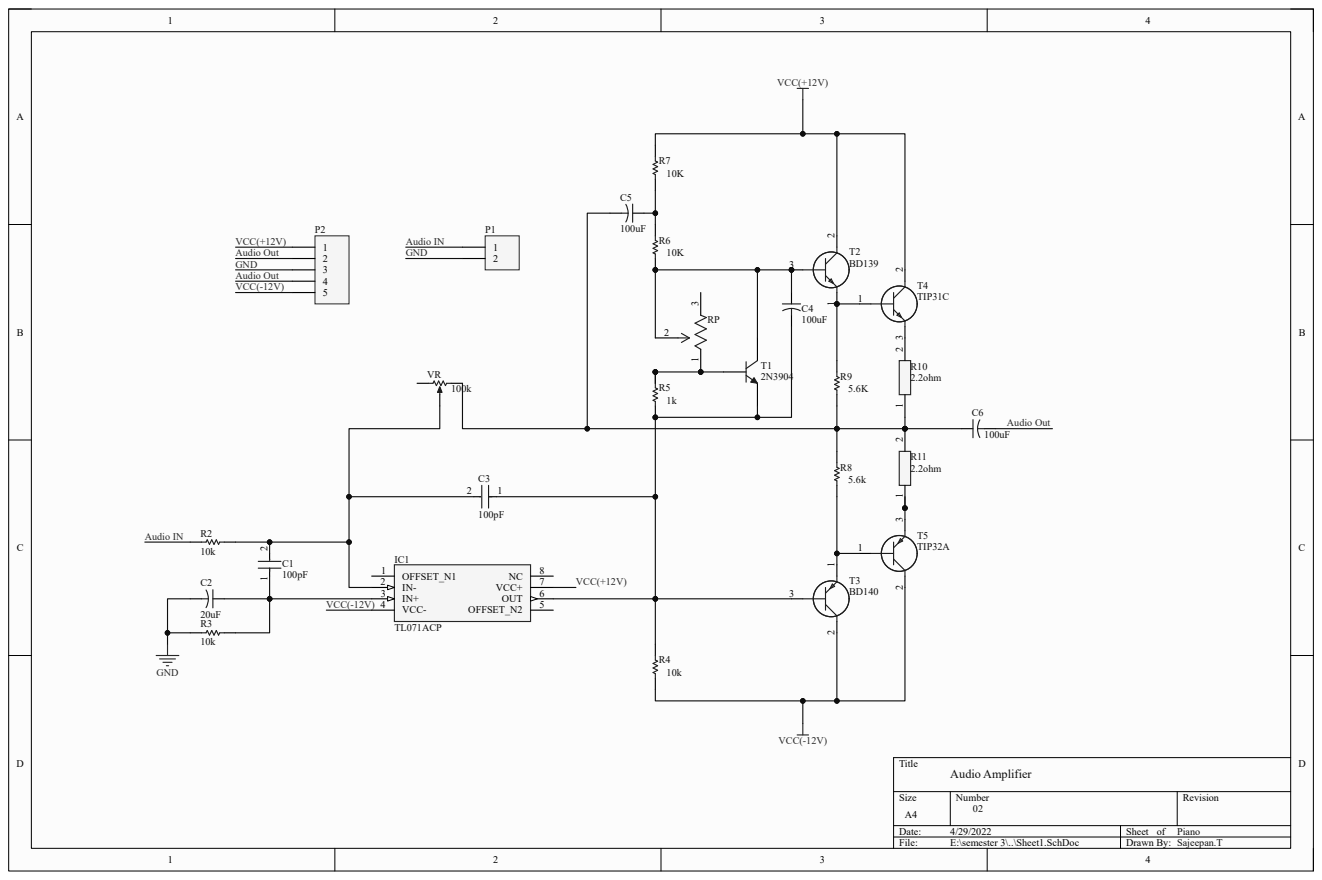
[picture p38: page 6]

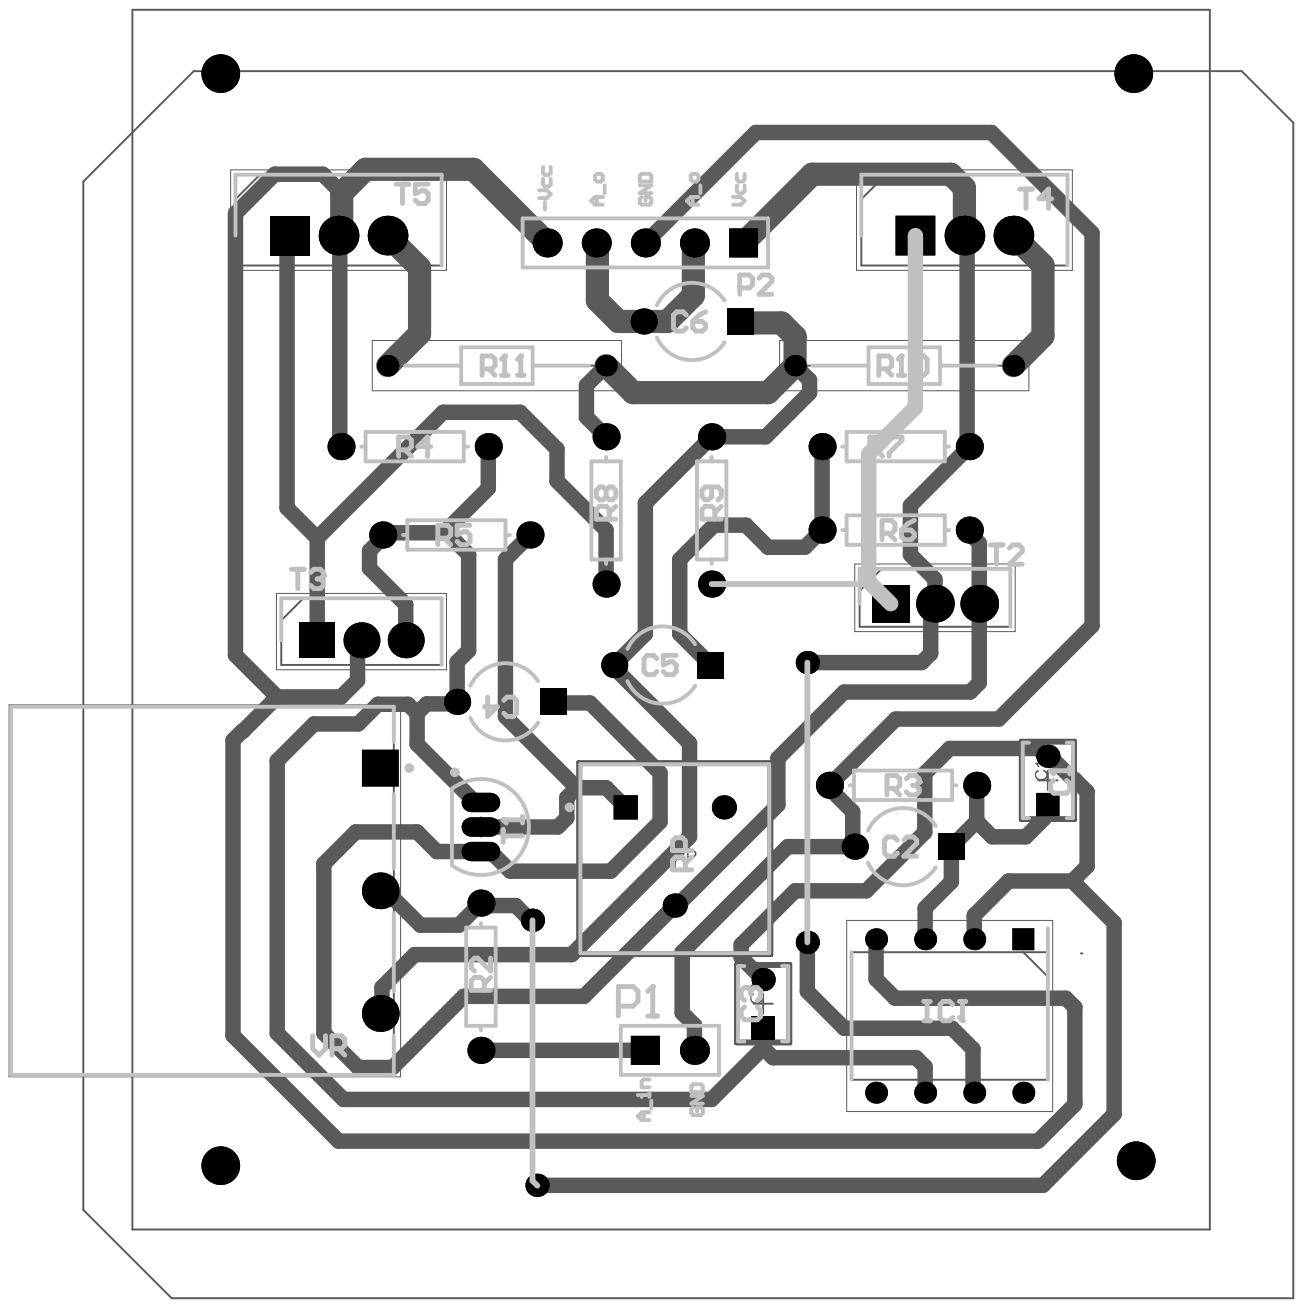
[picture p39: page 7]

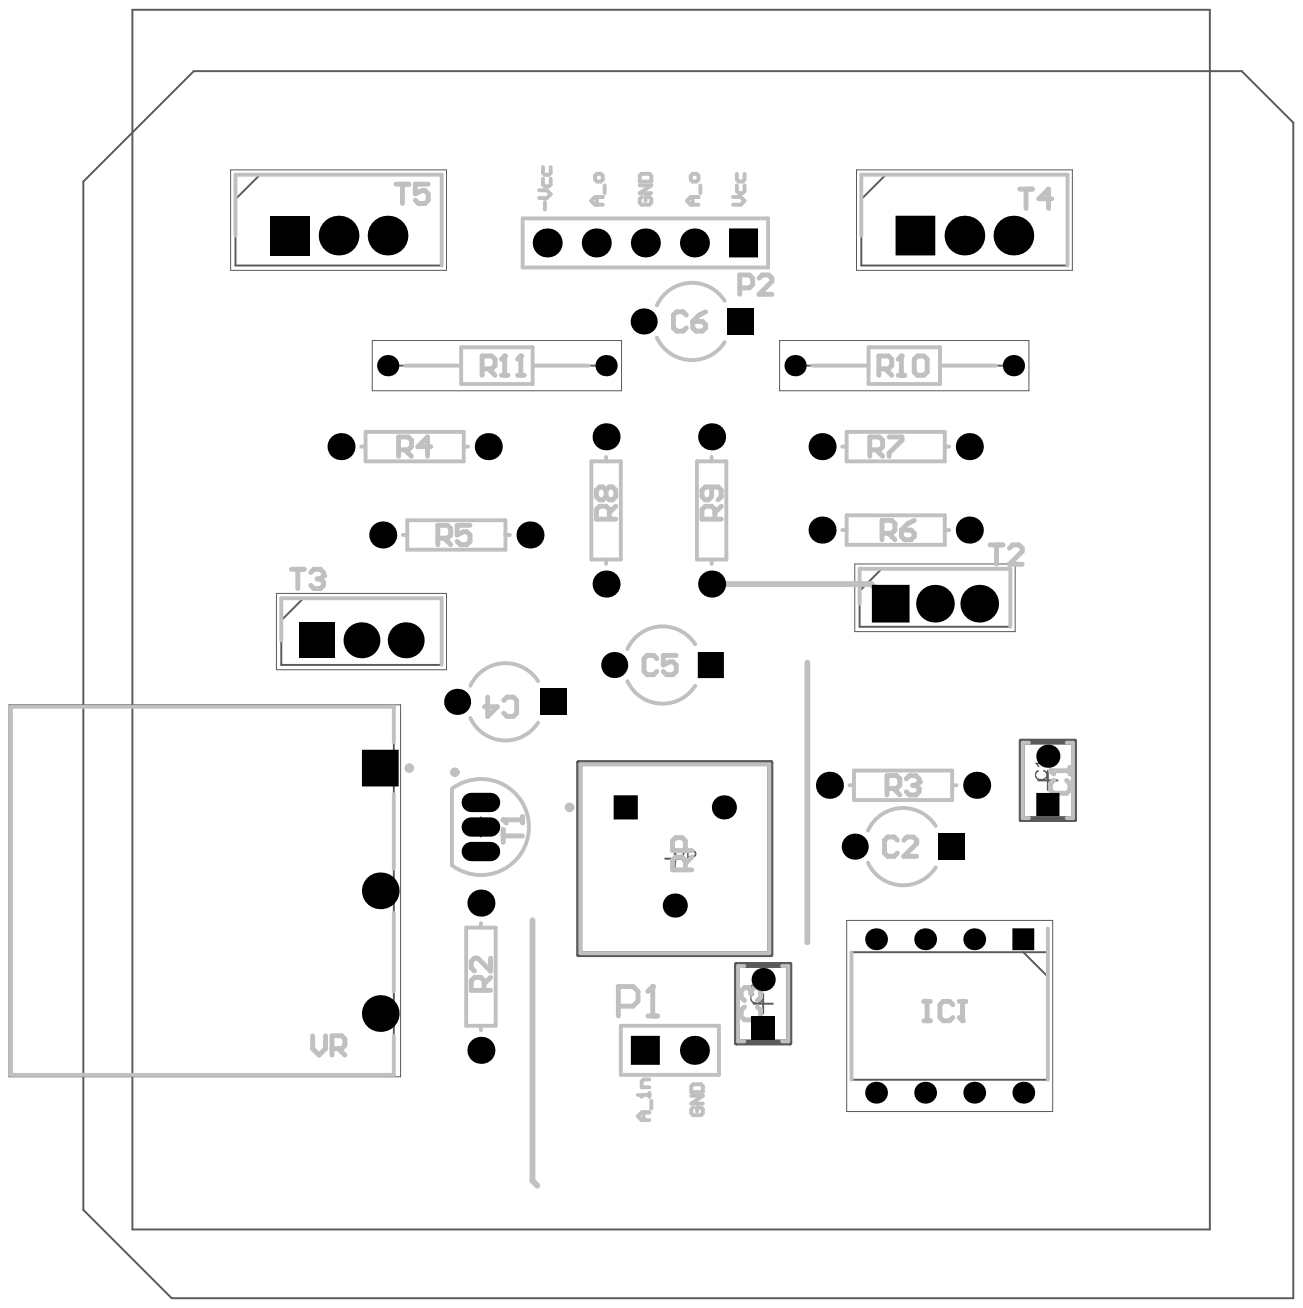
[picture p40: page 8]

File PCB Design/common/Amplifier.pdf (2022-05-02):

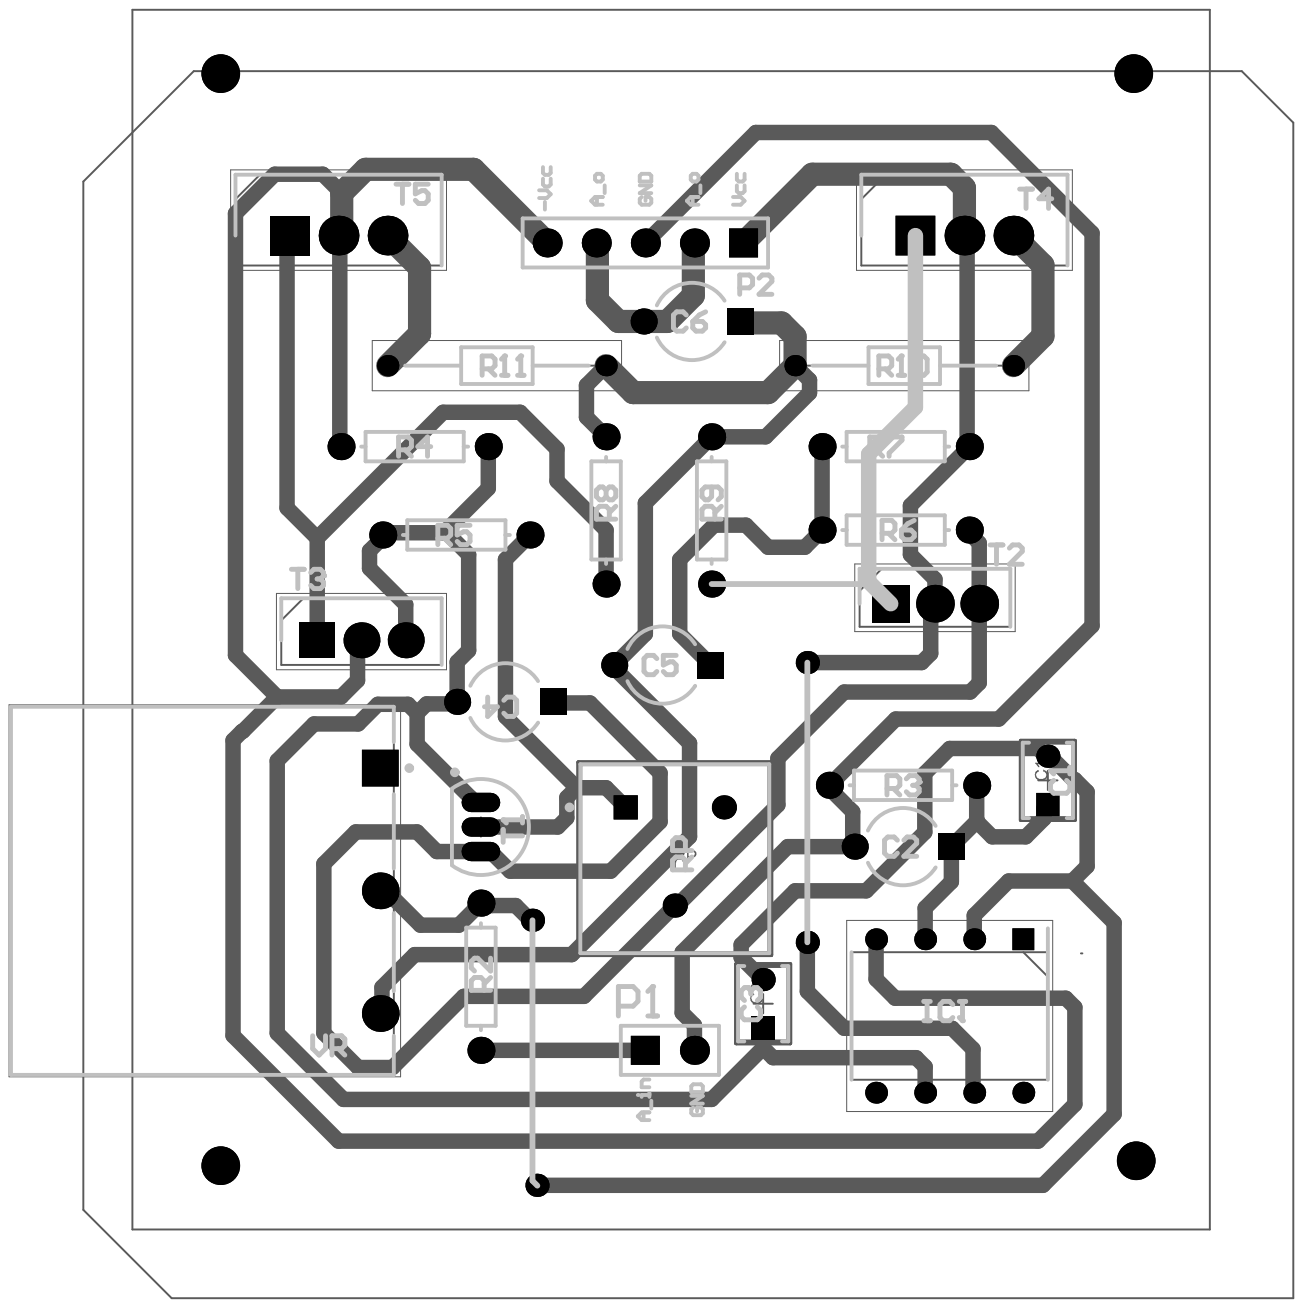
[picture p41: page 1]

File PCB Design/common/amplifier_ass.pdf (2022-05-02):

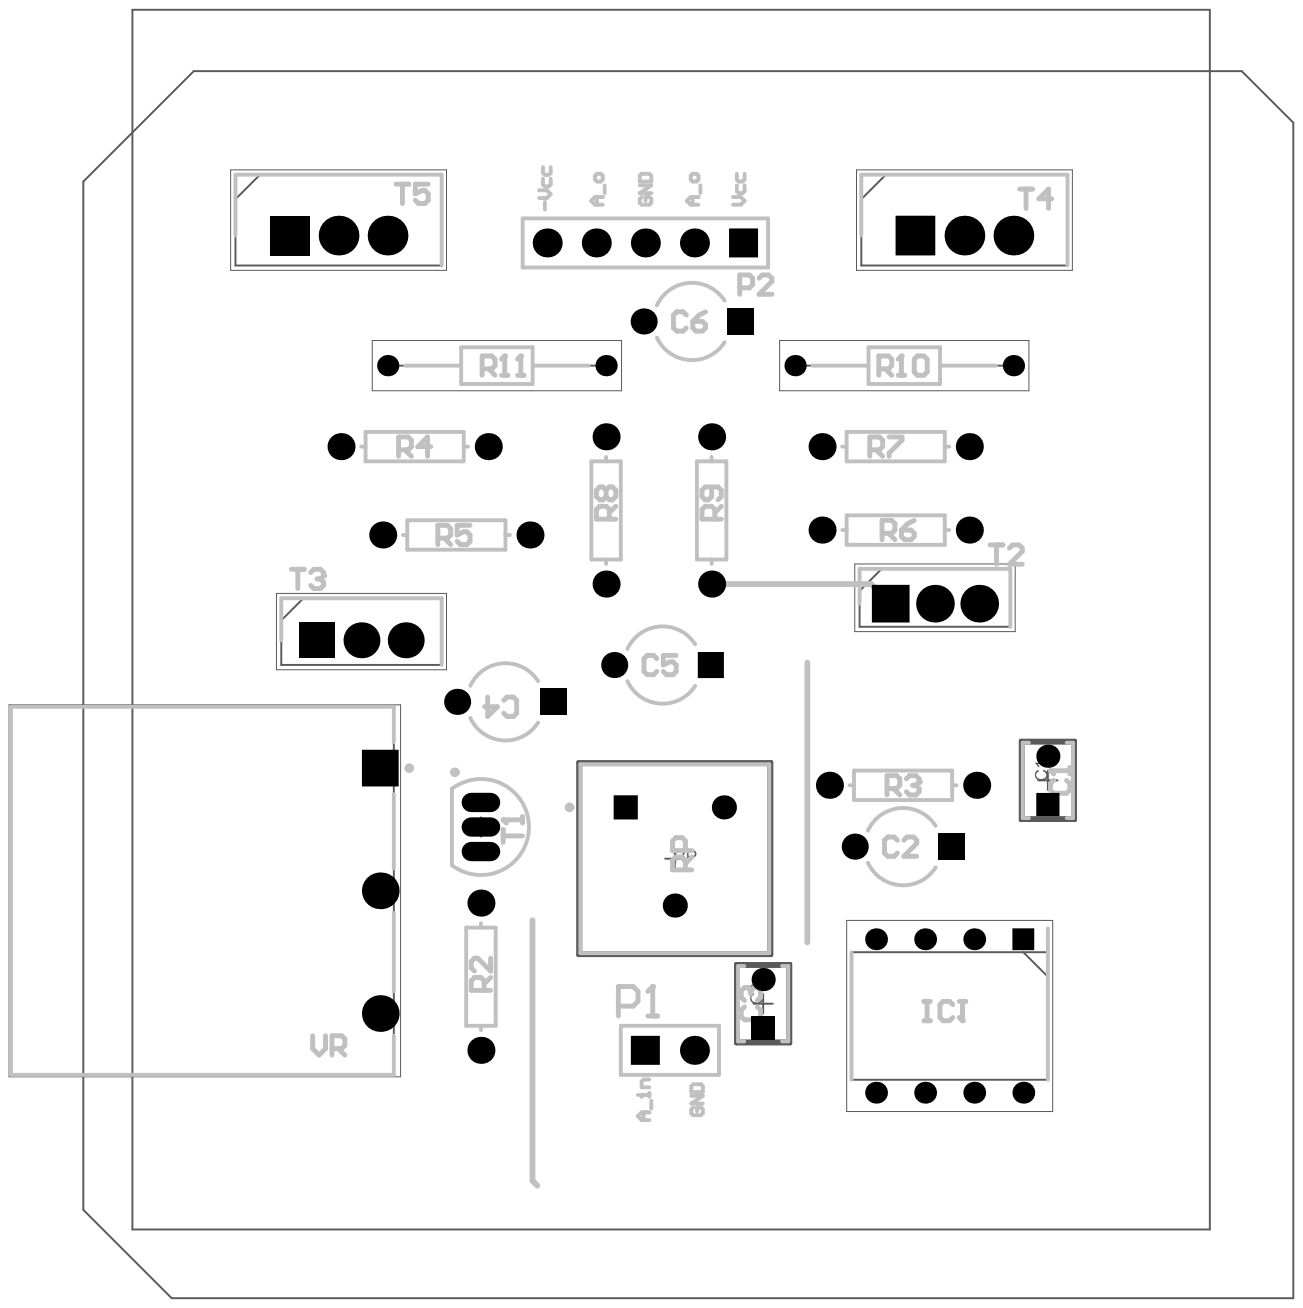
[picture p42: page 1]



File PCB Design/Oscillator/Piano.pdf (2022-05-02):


3 | | 4 -12

Size A4 | Number | Revision

Date: 4/29/2022 | Sheet of
File: E:\semester 3\..\Sheet1.SchDoc | Drawn By:


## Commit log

2022-05-02 Intial Commit
    [Audio amplifier.PrjPcb, PCB1.PcbDoc, PCB2.PcbDoc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]
2022-05-03 Edited Methodology
    [Piano.PrjPcb, Sheet1.SchDoc]
2022-05-07 Performed Correction on Current Value
